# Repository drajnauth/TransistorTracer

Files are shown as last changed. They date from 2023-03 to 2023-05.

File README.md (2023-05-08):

# TransistorTracer
Hardware and software for transistor tracer project.

KiCad PCB files for various versions of the transistor tracer as well as PlatformIO files for the firmware for the Arduino Nano.
The documentation folder contains a pdf version of a PowerPoint presentation regarding the tracer as well as build and operation instructions

A presentation introducing the tracer can be found at https://youtu.be/t6_chWRdSyg.  
This video is a bit dated and some of the information regarding the build, calibration and usage may have changed.

Currently only Hardware version 1 is documented and is working. Other versions are experimental and has not been verified. The software for experimental board versions may not work.

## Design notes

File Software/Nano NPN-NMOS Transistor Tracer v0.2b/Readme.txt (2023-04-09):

The current version is v0.2b
- New features include 
1) Ability to set output voltage.  Prior version only allowed setting of the PWM control voltage.
2) Moved some help messages and error message to flash memory to conserve ram.
3) Other minor changes.

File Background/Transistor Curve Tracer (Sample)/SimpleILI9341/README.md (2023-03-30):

# SimpleILI9341

This is a standalone library that contains both graphics functions
and the TFT ILI9341 driver library.

It is a "slow" version which shares the SPI bus politely with other devices.

It is written in plain C.

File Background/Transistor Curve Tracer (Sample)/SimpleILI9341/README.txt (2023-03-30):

This is a standalone library that contains both graphics functions
and the TFT ILI9341 driver library.

It is a "slow" version which shares the SPI bus politely with other devices.

It is written in plain C.

===============================================================

This library has been derived from the Adafruit_GFX and driver library with
further code from other authors.

===============================================================
Hereafter is the original README text for the Adafruit library:
===============================================================

This is the core graphics library for all our displays, providing
a common set of graphics primitives (points, lines, circles, etc.).

It needs to be paired with a hardware-specific library for each
display device we carry (to handle the lower-level functions).

Adafruit invests time and resources providing this open source
code, please support Adafruit and open-source hardware by
purchasing products from Adafruit!

Written by Limor Fried/Ladyada for Adafruit Industries.
BSD license, check license.txt for more information.
All text above must be included in any redistribution.

===============================================================

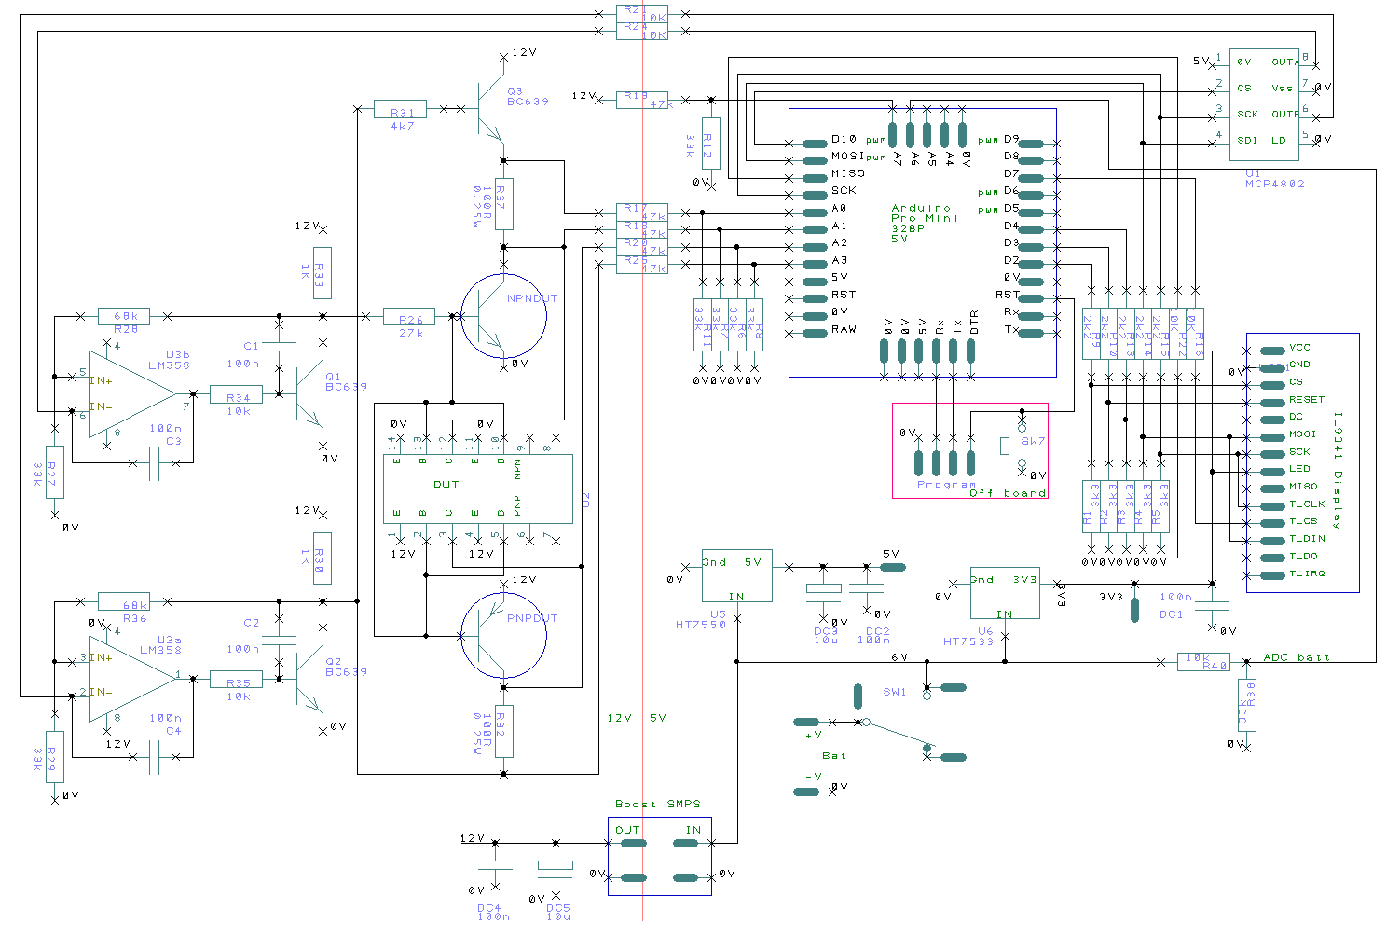
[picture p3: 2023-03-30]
Background/Transistor Curve Tracer (Sample)/ctcircuit.png

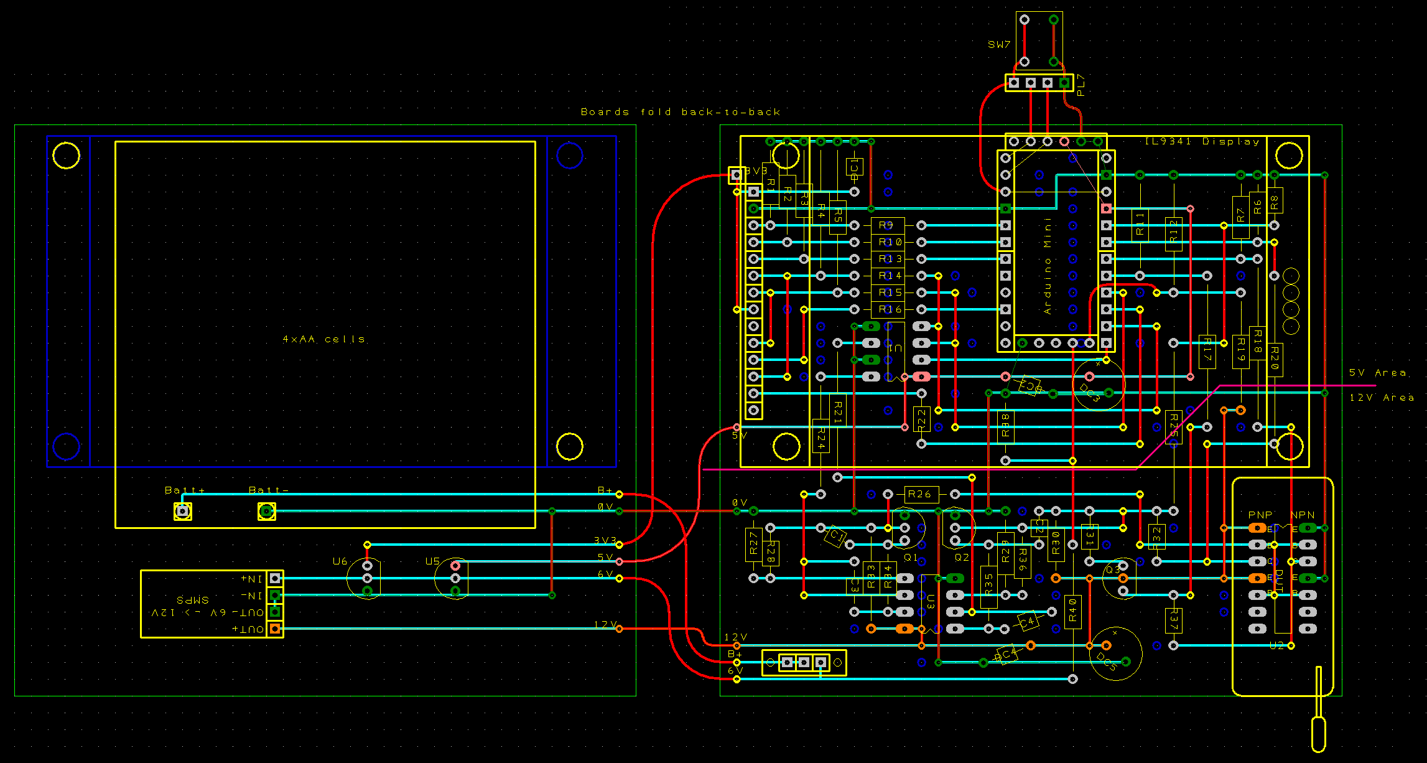
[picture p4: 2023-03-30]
Background/Transistor Curve Tracer (Sample)/ctstripboard.png

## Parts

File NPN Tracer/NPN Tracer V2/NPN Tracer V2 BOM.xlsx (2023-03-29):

Component Count: | 59
Ref | Qnty | Value | Cmp name | Footprint | Description
ADC1, ADC2, ADC3, ADC4, | 4 | 10K | R_Potentiometer_Trim | Potentiometer_THT:Potentiometer_Bourns_3296W_Vertical | Trim-potentiometer
C1, C2, C4, C5, C6, | 5 | 1n | C | Capacitor_SMD:C_1206_3216Metric | Unpolarized capacitor
C11, | 1 | 10u | C_Polarized | Capacitor_THT:CP_Radial_D8.0mm_P2.50mm | Polarized capacitor
C3, | 1 | 100n | C | Capacitor_SMD:C_1206_3216Metric | Unpolarized capacitor
C7, C8, C9, C10, | 4 | 33u | C_Polarized | Capacitor_THT:CP_Radial_D8.0mm_P2.50mm | Polarized capacitor
D1, D2, D3, D4, D5, | 5 | 4.9V | D_Zener | Diode_SMD:D_SOD-323 | Zener diode
D6, | 1 | PWR | LED | LED_THT:LED_D3.0mm | Light emitting diode
D7, | 1 | 1N5817 | 1N5817 | Diode_THT:D_DO-41_SOD81_P10.16mm_Horizontal | 20V 1A Schottky Barrier Rectifier Diode, DO-41
J1, | 1 | RC_SEL | Conn_01x03 | Connector_PinHeader_2.54mm:PinHeader_1x03_P2.54mm_Vertical | Generic connector, single row, 01x03, script generated (kicad-library-utils/schlib/autogen/connector/)
J2, | 1 | AD2 | Conn_01x02 | Connector_PinHeader_2.54mm:PinHeader_1x02_P2.54mm_Vertical | Generic connector, single row, 01x02, script generated (kicad-library-utils/schlib/autogen/connector/)
J3, | 1 | AD1 | Conn_01x02 | Connector_PinHeader_2.54mm:PinHeader_1x02_P2.54mm_Vertical | Generic connector, single row, 01x02, script generated (kicad-library-utils/schlib/autogen/connector/)
J4, | 1 | RB_SEL | Conn_01x03 | Connector_PinHeader_2.54mm:PinHeader_1x03_P2.54mm_Vertical | Generic connector, single row, 01x03, script generated (kicad-library-utils/schlib/autogen/connector/)
J5, | 1 | AD4 | Conn_01x02 | Connector_PinHeader_2.54mm:PinHeader_1x02_P2.54mm_Vertical | Generic connector, single row, 01x02, script generated (kicad-library-utils/schlib/autogen/connector/)
J6, | 1 | AD3 | Conn_01x02 | Connector_PinHeader_2.54mm:PinHeader_1x02_P2.54mm_Vertical | Generic connector, single row, 01x02, script generated (kicad-library-utils/schlib/autogen/connector/)
J7, | 1 | 5V | Conn_01x02 | Connector_PinHeader_2.54mm:PinHeader_1x02_P2.54mm_Vertical | Generic connector, single row, 01x02, script generated (kicad-library-utils/schlib/autogen/connector/)
J8, | 1 | PWR | Conn_01x03 | Connector_PinHeader_2.54mm:PinHeader_1x03_P2.54mm_Vertical | Generic connector, single row, 01x03, script generated (kicad-library-utils/schlib/autogen/connector/)
J9, | 1 | 13.8V MAX | Barrel_Jack | Connector_BarrelJack:BarrelJack_GCT_DCJ200-10-A_Horizontal | DC Barrel Jack
Q1, | 1 | 2SC5706 | 2SC5706-E | Custom_RF:2SC5706
Q2, Q3, Q4, Q5, Q6, | 5 | 2N3904 | 2N3904 | Package_TO_SOT_THT:TO-92_Inline | 0.2A Ic, 40V Vce, Small Signal NPN Transistor, TO-92
R1, R17, | 2 | 1K | R_US | Resistor_SMD:R_1206_3216Metric | Resistor, US symbol
R11, R13, | 2 | 20K | R_US | Resistor_SMD:R_1206_3216Metric | Resistor, US symbol
R15, | 1 | 33 | R_US | Resistor_THT:R_Axial_DIN0411_L9.9mm_D3.6mm_P7.62mm_Vertical | Resistor, US symbol
R16, | 1 | 10 | R_US | Resistor_THT:R_Axial_DIN0411_L9.9mm_D3.6mm_P7.62mm_Vertical | Resistor, US symbol
R2, R18, | 2 | 500 | R_US | Resistor_SMD:R_1206_3216Metric | Resistor, US symbol
R3, R4, R12, R14, R19, | 5 | 200 | R_US | Resistor_SMD:R_1206_3216Metric | Resistor, US symbol
R5, R6, | 2 | 237 | R_US | Resistor_SMD:R_1206_3216Metric | Resistor, US symbol
R7, R8, | 2 | 249 | R_US | Resistor_SMD:R_1206_3216Metric | Resistor, US symbol
R9, R10, | 2 | 56K | R_US | Resistor_SMD:R_1206_3216Metric | Resistor, US symbol
TB1, | 1 | Nano | ARDUINO_NANO | Microcontrollers:SHIELD_ARDUINO_NANO
U1, | 1 | LM7805 | LM7805_TO220 | Package_TO_SOT_THT:TO-220-3_Vertical | Positive 1A 35V Linear Regulator, Fixed Output 5V, TO-220
ZX1, | 1 | 16PIN ZIF | 16Pin ZIF | Custom_RF:16Pin ZIF

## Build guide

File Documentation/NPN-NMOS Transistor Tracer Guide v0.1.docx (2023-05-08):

NPN-NMOS TRANSISTOR TRACER MANUAL

HARDWARE: V1 Software: V0.2b

DRAFT DOCUMENT

Dave Rajnauth, VE3OOI

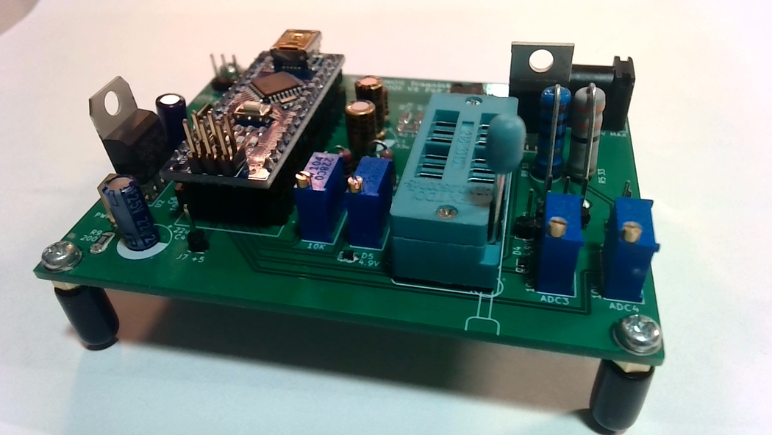
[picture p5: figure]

# Authors Notes

This device was designed only to perform analysis on NPN Bipolar Junction Transistors, N-Channel Enhancement Mode MOSFETS as well as Diodes including Zener Diodes.

Both the hardware and software are provided with NO WARRENTY or SUPPORT. You are on your own.

Various documents and files for this project are hosted on GitHub (https://github.com/drajnauth/TransistorTracer). This includes PCB boards (KiCad files and gerbers), software, and documentation (including this document).

This document includes very important information, and you need to read the contents carefully. Failure to read and follow the instructions in the document WILL cause headaches and may cause you to pitch the board against a wall.

This document uses the following syntax:

1. Anything in Red indicates something very important which could negatively impact the board. Please read carefully.
2. Anything in Deep Red indicates a particularly important note. Please pay attention.
3. Commands are highlighted in orange.
4. Changes to parameters defined by the Arduino #define directive are also highlighted in orange.

Finally, this is a powerful tool, and you are expected to understand how a transistor works and why you need the various traces detailed in this document. It has features which can make your day or frustrate the heck out of you.

# Hardware Build Notes

1. Have a copy of the schematic available during the build.
2. DO NOT INSERT THE ARDUINO AND POWER UP (i.e., Apply Vcc) BEFORE CALIBRATION IS DONE
3. Do your best to get parts as labelled.
4. Early versions of boards have incorrect silkscreen values for POTS. They MUST be 100K.
5. The TIP120 can be replaced with a 2SC5706 power transistor.
6. The 1N5817 can be replaced with any 1 Amp Shottky Diode
7. The board can be powered from either J8 or J5. Maximum voltage is 14 V. Exceeding this could damage your Arduino.
8. R1, R3, R6, R7, R10, and R11 resistors cannot be substituted and need to be as close as possible to the indicated values. Substituting resistor values could dramatically alter the performance of the device.
  - R1 and R3, in combination with C1 and C2, are part of a low pass filter that converts an Arduino generated PWM signal into a DC voltage.
  - R6 and R7 set the gain for the LM386 Opamp to amply the PWM generated DC voltage to Vcc to control the TIP120/2SC5806 power transistor.
  - R10 and R11 form a voltage divider to allow the Arduino to measure the value of Vcc.
9. Capacitors C1, C2, C7, C8, C9 and C10 cannot be substituted and need to be as close as possible to the indicated values. Other capacitors can use similar values but not exact values.
  - C1 and C2 are part of a low pass filter to convert the Arduino generated PWM signal to a DC value.
  - C7, C8, C9 and C10 also form a low pass filter to smooth out the voltages read by the Arduino ADC. Values too large here will result in ADC errors.
10. The D3, D4, D5, and D6 4.9V Zener diodes are optional and are there to protect Arduino ADC from overvoltage. They are not necessary for the operation of the device.
11. Resistors R10 and R11 form a voltage divider to allow the Arduino to measure the value of Vcc. If you change these values, ensure the ratio will allow 14V to deliver about 4.8V to the Arduino. Measure and note the values, rounding to the nearest whole number, of the resistors you use. You will need to enter them in the Arduino code during the calibration.
12. R4, R5 and R8 set the maximum current to the base/gate or to the collector/drain of the transistor under test. You can substitute values here. Keep R4 close the 500R (i.e., within 10 or 20R). R5 and R8 must be 2W resistors. They dissipate heat from several hundred milliamps of current. Measure both resistors with Volt Ohm Meter and note the values, rounding to the nearest whole number, of these resistors. You will need to enter them in the Arduino code.
  - You are provided with two resistor values to limit the current delivered to the collector/drain. You can select R5 or R8 via jumper J4 (RCSEL). Whenever you change this jumper you must change the resistor value via the Arduino CLI. See the CLI Resistor Configuration Commands section.
13. Solder all SMT parts first.
14. Solder all through hole components from the underside
  - Arrange the pots such that turning clockwise increases the resistance between the wiper and the grounded leg.
15. Once you are finished remove all jumpers from header pins. Do NOT insert the Arduino. Power up and check LED operation and check for appropriate voltages at Arduino +5V pin and LM358 Vcc pin (pin 8).
16. Disconnect power and proceed to calibration.

# Calibration

Note the instructions below are for hardware Version 1 and software version 0.1b.

1. DO NOT CONNECT ARDUINO AND POWER UP THE BOARD BEFORE CALIBRATION IS DONE. Failure to do so may result in damage to the Arduino.
2. For all measurements, use one consistent VOM. Try not to use different meters as they may introduce additional errors.
3. Before powering up Arduino, you need to calibrate pots to not damage the Arduino’s ADC pins.
4. Remove Arduino. Remove all jumpers from all trim pot jumper headers pins.
5. Connect Vcc to the board and measure the voltage at the +5V terminal pin (J7). Record the voltage.
6. Connect a jumper wire from +5V terminal to each pot’s jumper “+” pin (J1, J2, J6, J3). “+” is marked on the silkscreen. The plus pin is connected to the top end of the pot. The wiper is connected to the Arduino’s ADC and forms a voltage divider.
  - Adjust each pot until you get as close as possible to 1.75V output at the pot’s wiper.
7. Verify the voltage at ADC 0 pin and Digital Pin 12 (or junction of R10 and R11) is below 5 Volts. If this voltage is above 5V, you need to verify the value of Vcc (less than 14V) and the values of R10 and R11. Ensure solder joins are good.
  - Note that Resistor R10 and R11 form a voltage divider to convert Vcc to a voltage below 5V. The Arduino reads this voltage to ensure a proper Vcc is applied to the board.
8. Once all pots are adjusted and the Vcc voltage divider is working, then there is little danger in damaging the Arduino’s ADC. Insert Arduino and load the code. See the software loading section of this document.
9. Connect via TTY console to Arduino. Enter the C R command to display all ADC values from each pot.
10. Note that each pot has ADC1, ADC2, ADC3, ADC4 marked on the silkscreen. Each jumper associated with the pot is marked as AD1, AD2, AD3, AD4. This corresponds to the ADC number on the Arduino.
11. Connect 5V to the same jumper in step 3. Note the ADC number of the jumper and pot.
  - Adjust the pot’s wiper (fine adjust needed) until the corresponding ADC displayed by the Arduino is EXACTLY 364. Repeat for all jumpers/pots.
  - Measure and record the voltage at the wiper of the adjusted pot. It may be slightly different from the initial 1.75V setting.
  - Enter the R command to reset the Arduino when done.
12. Complete and record the following calculations for each pot:

Note V(wiper) is the updated wiper voltage you measured in the prior step and V(applied) is the voltage you measured previously at the +5V pin (J7). ADC_Value is the value of the ADC that you set the pots to (i.e., 364).

For the example calculations below V(wiper)=1.75, V(applied)=5, ADC_Value=364. Subsititue the values you measured.

  - Calculate VOLTAGE_DIVIDER = V(wiper)/V(applied)

e.g., 1.75/5 = 0.357

Note V(wiper) is the updated voltage you measured in the prior step.

  - Calculate ADC_CONVERSION = ADC_Value/V(wiper) e.g., 364/1.75 = 208.0
  - Calculate VOLTAGE_CONVERSION = VOLTAGE_DIVIDER * ADC_CONVERSION e.g., 0.357*208 = 78.0
13. Take the VOLTAGE_CONVERSION and update the #define ADC_CONVERSION ((float)78.0) in the defines.h file. This can be done after loading the program into the Arduino IDE.
14. Using the measured resistor values for R10 and R11 calculate the voltage divider for the Vcc voltage sensing. Calculate the divider R11/(R11+R10). Next calculate the ADC conversion ratio by taking the voltage measured at the J7 pin (+5V pin) and dividing it by 1024. Update the #define VOLTAGE_SENSE_CONVERSION parameter in the defines.h file.

For example,

Suppose resistor divider measurements are R10 is 991 and R11 is 497. Divider is 497/(497+991)=0.3340

Suppose voltage at J7 pin is 4.88V so ADC Voltage conversion is 4.88V/1024 = 4.766mV. i.e., 1 ADC count is 4.766mV

With resistive divider each count is 4.766mV/0.3340 = 14.26mV = 0.01426V

#define VOLTAGE_SENSE_CONVERSION 0.01426

15. Use your measurements for the Base and Collector resistors to update the following defines in the defines.h file.

For example, RC resistors are 32 and 10. The base resistor is 462.

#define RC_RESISTORHIGH 32

#define RC_RESISTORLOW 10

#define RB_RESISTOR 462

1. Reset the Arduino and measure the max voltage generated by the Arduino PWM circuit for the base/gate and collector/drain. Ensure no jumpers are connected. Enter the P 3 255 command and measure and record the voltage after the 200R resistor connected to D3 pin (i.e., the side of the R1 200R resistor connected to the electrolytic capacitor). Reset the Arduino and repeat for pin 10. Enter the P 10 255 and measure and record the voltage after the R3 200R resistor is connected to D10 pin. Again, measure the voltage at the side of the resistor that is connected to the electrolytic capacitor. Update the following defines in the defines.h file with the voltages you measured. In the example below, 4.6 volts was measured.

#define MAX_VC_VOLTAGE 4.6

#define MAX_VB_VOLTAGE 4.6

2. Save all modified files. Compile and load the Arduino program before continuing. The above defines must be in place.
3. Complete the following. DO NO RESET OR POWER OFF ARDUINO UNTIL ALL STEPS BELOW ARE COMPLETE. Failure will result in redoing the steps.
  1. Set the base resistor value using the S R B nnnn command where nnnn is the resistor value that you measured and entered previously. E.g., enter S R B 462 to set the base resistor to 462.
  2. Set the jumper J4 (RCSEL) to a resistor for the sweep. Use the S R C nnnn command to define the Collector resistor nnnn that the jumper has selected. E.g., Enter S R C 10 to set the collector resistor set by the jumper J4 to be the 10R resistor. Alternatively, enter S R C 32 if the jumper J4 has selected the 32R resistor.
  3. Connect Vcc to the board. If you change Vcc, the following calibration step needs to be repeated. E.g., if you use 12V to calibrate the board and you connect 13.8V in the future, the board will need to be recalibrated for the new Vcc value.
  4. The final calibration step is to get the Arduino to measure the min and max voltages available when generating a trace. Insert jumpers in J1, J2, J6, & J3. Ensure there is nothing connected to the ZIF socket. Enter the C M command. This takes a few minutes to complete. If you miss this step, the tracer will not work properly.
4. Update the EEPROM with the configuration by entering the E W command. If you miss this step, the tracer will not work properly next time it’s restarted. The Arduino will now power up with the values you defined above.
5. Your transistor curve tracer (V1) is now ready.

# Transistor Tracer Software

The transistor tracer needs two software components:

1. The Tracer uses an Arduino Nana with special software that controls the hardware and produces the various traces.
2. The Tracer also requires an external plotting program. A small versitile Python program was written to generate generic plots. This program is one option that can be used to generate plots on the fly. A second option is to use another program such as Microsoft Excel or Apache OpenOffice Calc to generate the charts. The Arduino software simply displays the data to be charted on the serial console which can be copied and pasted into any other charting program.

## Arduino Nano Firmware

This software for the Arduino Nano was written using Visual Code with the PlatformIO plugin instead of the Arduino IDE. The transistor tracer software is FULLY compatible with the Arduino IDE. If you are familiar with PlatformIO, I suggest you create a new Visual Studio project for Platform IO and load the source files. Directions to accomplish this using Visual Studio is beyond the scope of this document. Instead, directions for loading using Arduino IDE will be given below.

It is assumed that you understand how to use the Arduino IDE to compile and load sketches on Arduino boards. If you are new to using the Arduino IDE, I suggest that you review tutorials on the internet to prepare you. However, I strongly suggest you seek assistance from someone that is familiar with the Arduino IDE to reduce your stress and increase your chances of success.

Arduino IDE Loading Instructions

1. From the https://github.com/drajnauth/TransistorTracer github repo, download the zip file for the entire repo. This will duplicate all files in the repo.
2. Create a directory on your local hard disk and provide a name that you would like to call the Arduino sketch (e.g., “TransistorTracerSketch”).
3. Copy all the files from the “Software/Nano NPN-NMOS Transistor Tracer v0.2b” directory to the above created directory.
4. Rename the main.cpp file so it matches the directory name you created with an .ino extension (e.g. TransistorTracerSketch.ino)
5. Double click the ino file or open the sketch in your Arduino IDE.
6. Ensure you have the Arduino Nano board selected and the appropriate com port selected. Complete a test compile to ensure it compiles.
7. Load the software on the nano.
8. Once the software is loaded, the onboard LED should blink every second indicating Vcc is not connected. If you connect via the Arduino Console, there will be a Vcc error displayed. This is normal until the Nano is inserted onto the tracer board and the board is powered up. DO NOT INSERT THE ARDUINO AND POWER UP THE BOARD BEFORE CALIBRATION IS DONE.

## Microcontroller Console Python Program

The console program was written to plot data from any microcontroller. It WAS NOT written exclusively for the transistor tracer. The program was meant to be a quick and dirty program that can plot charts from any TTY (serial port) connected microcontroller. A display could have been incorporated onto the Arduino, however this would make this project complex, and the Nano software would be a beast to write and maintain.

Figure 1: Sample Plot from Python Program

You can also copy and paste the generated data from the Arduino Console into Microsoft Excel or Apache OpenOffice Calc and generate the charts yourself. The Arduino simply outputs the data to the console and the python program captures it, stores it into a buffer and then plots the data for you.

A presentation was provided giving a high-level overview of how this program works. The associated ppt has been included in the documentation folder and you should refer to this regarding how to use the python program.

If you are familiar with python and loading libraries, then load the source code and associated libraries. Python files are in the “Software/Python Microcontroller PC Console” directory.

However, if you are not familiar with python an executable file is provided in the python directory. The file’s extension is. ex_. Once you have this file on your local PC, rename the file to be .exe. Some browsers will block you from downloading executable files and this is a crude attempt to circumvent such checks.

Simply double click the executable and accept the warning about the software being unverified. Do this at your own risk. The software I placed on my repo is free of malware.

Note that the program will give an error if no com ports were detected. You must plug in your Arduino to the USB port before running the console program.

Figure 2: Python Program Interface

# Command Line Interface

The Arduino has a command line interface (CLI) which is accessible via a terminal emulator connected to the Arduino USB connection. That is, a serial comport connection from your PC using either the Arduino console program or the Python console program. The CLI may be accessed via any TTY console program (e.g., putty). This is the only way to control the transistor tracer.

## Performing Sweeps

1. The transistor tracer generates a trace by sweeping a set of voltages. These DC voltages are generated by the PWM circuit.
  - There is a base/gate PWM voltage (Pin 3) that is applied directly to the transistor under test.
  - There is a Vcc PWM voltage (Pin 10) that is amplified by the LM358 opamp and a high-power transistor (TIP120 or SC5706) in a common emitter configuration.
2. There is a “Control” voltage. There is also an “Output” voltage.
  - The “Control” voltage is generated by the Arduino PWM circuit.
  - The “Output” voltage is delivered to the device under test (DUT).
  - The conversation between the “Control” and “Output” voltages is calculated when you perform a calibration.
3. The arduino uses the “Control” voltage to sweep voltages to complete a trace. It does not use “Output” voltages. “Output” voltages are measured by the ADCs.
4. Since the base/gate “Control” voltage is fed directly to the transistor under test, the base/gate voltage is essentially the “Output” voltage to the transistor. However, since the Vcc “Control” voltage is amplified, the “Output” voltage fed to the collector/drain of the transistor under test is larger than the “Control”.
5. When you set voltage ranges, you are setting the “Control” voltage that the Arduino outputs. However, you can set the “Output” voltage range and the Arduino will calculate the “Control” voltage for you and use that.
6. Normally, the calibration will calculate the minimum and maximum voltages available and use those values for the sweep. However, you can manually set the “Control” or “Output” sweep voltages using the S I or S O commands. Once again, if you set “Output” voltages, the Arduino converts this into “Control” voltages which are used for tracing.
7. You can also manually set the voltage delivered to the DUT using the S V command. This only uses the “Control” voltage. However, this is a one-time setting. It’s not used in a sweep. BE CAREFULL SETTING VOLTAGES MANUALLY – you could destroy (i.e., burn out) the collector resistor or the transistor under test if you exceed its maximum ratings.
  - When you set voltage ranges, you are restricting values that the Arduino will deliver to the DUT. This restricts values that the S V command can use.
8. MOST IMPORTANT: Voltages are entered in mV (Milla Volts). i.e., to specific 1 volt you enter 1000 mV. The CLI does not support floating point or real numbers. Only integers can be entered.

The following diagram details the pin out for the Zif sockets. Ensure transistors are connected properly. Incorrect orientation would result in “wonky” charts and in extreme cases damage to the transistor or resistors on the board.

## CLI Summary

Commands listed below follow a specific syntax. Anything in [ ] means that additional input is needed. Either a sub command or a number. Note that numbers MUST BE INTEGERS. Floating point or real numbers are not supported. For example, to ensure a real number multiply it by 1000 e.g., voltages are entered in millivolts.

The | character indicates an or condition. Either of the values on either side of the | can be entered buy not both. E.g., C [R|M] means that C R or C M can be entered i.e., R OR M can be entered.

The Arduino tracer store it configuration to is local EEPROM. The EEPROM is not updated when configuration is changed. You must explicitly save the running configuration to the EEPROM configuration.

Note that Gate-Base, Collector-Drain, and Emitter-Source are the same. i.e., anything defined for base will also apply to gate.

- H Help – Command summary
- C Display current Calibration
- C [R|M] Calibrate commands
  - R display raw ADC values repeatedly until the arduino is reset
  - M identifies the min and max voltage that can be provided to the transistor under test
- D Set default values. Resets all running configuration to default.

Reboot or reset to restore the EEPROM calibration.

Run the C M command to reset the min and max available voltages.

- E [I|R|W] Manage EEPROM
  - I is used to initialize the EEPROM to factory default
  - R is used to read and use the configuration in EEPROM
  - W is used to write the current running configuration to EEPROM. This will be loaded when arduino is powered on or reset.
- M Measure and display voltages
- P [3|10] [255] Set PWM on pin 3 or pin 10 to duty cycle from 1 to 255
- R Reset the arduino. EEPROM configuration is loaded.
- S V [B|C] [v] Manually set voltage v in mV
  - B is used to set the voltage for the Base/gate pin.
  - C is used to set the voltage for the collector/drain pin.
- S U [D|M|U] Set default units for output. Decimal [D], Milla[M] or Micro [U]
- S I [B|C] [min] [max] Set input or control min max voltage generated by Arduino
  - B sets the base/gate control voltage to sweep from min to max in mV.
  - C sets the collector/drain control voltage to sweep from min to max in mV.
  - Increment auto calculated based on number of data point “P” defined below
- S O [B|C] [min] [max] Set output min max voltage delivered to transistor to sweep
  - B sets the base/gate voltage to sweep from min to max in mV.
  - C sets the collector/drain voltage to sweep from min to max in mV.
  - Increment auto calculated based on number of data point “P” defined below
- S R [B|C] [r] Set Base or Collector resistor value to r.
  - r must be configures during calibration.
  - For collector/drain, resistor is set by jumper J4 (RCSEL). Base/gate resistor is fixed and cannot be changed for this version of hardware board. Subsequent hardware versions will have different base/gate resistors.
- S P [B|C] [n] Set number of data points n to sweep between max and min
  - This is used to calculate the increment between min and max voltages defined above
  - B sets the number of data point to sweep for base/gate voltages/currents
  - C sets the number of data point to sweep for collector/drain voltages
- T N [I|IV|O|B|BC|R|G] Trace NPN Transistor
  - I - Perform an input trace. Trace Vbe vs Ic
  - IV – Perform an input trace with Vce. Trace Vbe vs Vce
  - O – Perform an output trace. Trace Vce vs Ic for various Ib values
  - B – Perform a beta trace. Trace Ib vs B
  - BC – Perform a beta trace. Trace Ic vs Bc
  - R – Perform a re trace. Trace Vbe vs re
  - G – perform a transconductance trace. Trace Vbe vs gm
- T F [I|IV|O|K|G|R] Trace N Chan MOSFET
  - I - Perform an input trace. Trace Vgs vs Id
  - IV – Perform an input trace with Vgs. Trace Vgs vs Vds
  - O – Perform an output trace. Trace Vds vs Id for various Vgs values
  - K – Perform a FET constant K trace. Trace Id vs K
  - G – perform a transconductance trace. Trace Vgs vs gm
  - R – Perform a Rds trace. Trace Vgs vs Rds
- T [I|O] Trace Diode
  - I – perform an input trace. Diode inserted between base/gate and emitter/source pins.
  - O – perform an output diode trace. A resistor must be connected in series with resistor to allow the Rc resistors not to burn up. Use resistor around 200R.

## CLI Calibration Commands

This section summarizes all the commands available for calibration and configuration viewing. There are 3 commands available.

C

Display current Calibration values and the defined configuration that is currently running. This may not show the configuration that is stored in the EEPROM. E.g., you changed the configuration and did not write it to the EEPROM.

C M

Connect the Tracer to Vcc with empty socket (nothing connected) to determine the voltage sweep range for base/gate voltage and collector/drain voltage. It also calculates the conversion constants to generate output voltage as a function of control voltage.

C R

Connect the Tracer to Vcc with empty socket (nothing connected). Enter this command to display the raw ADC values repeatedly. The first column is the Vcc voltage pin (AD4), next is Vc voltage pin (AD3), Vbcontrol pin (AD1), Vb voltage pin (AD2). Press the reset button or enter the R command to reset the Arduino and stop the display.

## CLI Resistor Configuration Commands

This section summarizes all the commands available for changing the resistor values.

S R C nnnn

Use the resistor value for the collector/drain (R5 or R5) specified by nnnn. Note that nnnn must be a integer number (i.e., not real or floating point number) that was set in the defines.h file during the calibration.

S R B nnnn

For this version of the transistor tracer hardware, the base/gate resistor is fixed and this command is unsupported. It will be available for a subsequent hardware revision where you can select the base/gate resistor.

S R

Display the current base/gate and collector/drain resistor that the Arduino will use for current calculation.

## CLI NPN Sweep Commands

The T command is used to complete Traces. The T N command is used to complete NPN Transistor traces.

1. The following traces use the configured min and max voltages. You can adjust sweep voltages and number of data points (resolution) to be taken during a sweep. Use the S M command to adjust min & max voltages for and S P to set data points.
2. The following below outlines the various traces:
I. Input Trace: T N I
  - This command sets the Vcc voltage to the maximum available voltage and then sweeps the base voltage from configured min to max at define inc (resolution). It prints out Vbe vs Ic.
II. Input Trace: T N I V
  - This command is the same as above except it prints out Vbe vs Vce.
III. Output Trace: T N O
  - This command sweeps the base voltage from configurated min to max with inc. For each base voltage, it then sweeps Vcc from configured min to max at defined inc. For each base voltage it prints out Vce vs Ic in the form Ib, Vce, Ic.
IV. Beta Trace: T N B
  - This command sets the Vcc voltage to the maximum available voltage and then sweeps the base voltage from configured min to max at define inc (resolution). It calculates transistor beta and prints out Ib vs Beta.
V. Beta Trace: T N B C
  - This command is the same as above except it prints out prints out Ic vs Beta.
VI. Beta Trace: T N R
  - This command sets the Vcc voltage to the maximum available voltage and then sweeps the base voltage from configured min to max at define inc (resolution). It calculates transistor re (intrinsic resistance) and prints out Ic vs re.
VII. Beta Trace: T N G
  - This command sets the Vcc voltage to the maximum available voltage and then sweeps the base voltage from configured min to max at define inc (resolution). It calculates transistor transconductance and prints out Ic vs gm

## CLI N-Channel MOSFET Sweep Commands

The T command is used to complete both NPN and N-Channel Enhancement Mode MOSFET Traces. The T F command is used to complete N channel MOSFET traces.

1. The following traces use the configured min and max voltages. You can adjust sweep voltages and number of data points (resolution) to be taken during a sweep. Use the S M command to adjust min & max voltages for and S P to set data points.
2. The following below outlines the various traces:
I. Input Trace: T F I
  - This command sets the Vcc voltage to the maximum available voltage and then sweeps the gate voltage from configured min to max at define inc (resolution). It prints out Vgs vs Id.
II. Input Trace: T F I V
  - This command is the same as above except it prints out Vgs vs Vds.
III. Output Trace: T F O
  - This command sweeps the base voltage from configurated min to max with inc. For each gate voltage, it then sweeps Vcc from configured min to max at defined inc. For each gate voltage it prints out Vds vs Id in the form Id, Vgs, Id.
IV. Intrinsic Resistance Trace: T F R
  - This command sets the Vcc voltage to the maximum available voltage and then sweeps the gate voltage from configured min to max at define inc (resolution). It calculates transistor re (intrinsic resistance) and prints out Id vs Rds.
V. Transconductance Trace: T F G
  - This command sets the Vcc voltage to the maximum available voltage and then sweeps the gate voltage from configured min to max at define inc (resolution). It calculates transistor transconductance and prints out Id vs gm
VI. Transconductance Trace: T F K
  - This command is the same as above except it it calculates transistor transconductance constant K and prints out Id vs K.

## CLI Diode Sweep Commands

The T command is used to complete both NPN and N-Channel Enhancement Mode MOSFET Traces. As well as diode Traces. The T D command is used to complete diode traces

The following traces use the configured min and max voltages. You can adjust sweep voltages and number of data points (resolution) to be taken during a sweep. Use the S M command to adjust min & max voltages for and S P to set data points.

1. Note that the diode MUST be oriented correctly in the socket.
2. The following outlines the various traces:
  i. Input Trace: T D I

This traces the turn on voltage of the diode for it to conduct from its anode to cathode terminals. The diode must be connected between the base/gate socket and ground. The cathode is connected to emitter/source socket (ground). For a Zener diode, it’s reversed, the cathode is connected to the base. The collector/drain pin of the zif socket MUST be unconnected. This command sweeps the base/gate voltage from configured min to max at define inc (resolution). It prints out Vb vs Id

  ii. Output Trace: T D O

This trace identifes the voltage drop across the diode’s anode to cathode. The diode will need a resistor connected between the cathode and the emitter/source socket (ground). The resistor is selected to NOT exceed the maximum current the diode can handle. The resistor also protects the Arduino pin used for base PWM output (pin 3). Failure to add a resistor could cause damage to the Arduino. This command sets the base/gate voltage Arduino pin to zero to sink current. It then sweeps the Vcc voltage from configurated min to max with inc. For each Vcc voltage, it measures the voltage drop across the collector/drain to the base/gate sockets along with current. It prints out Vf vs I.

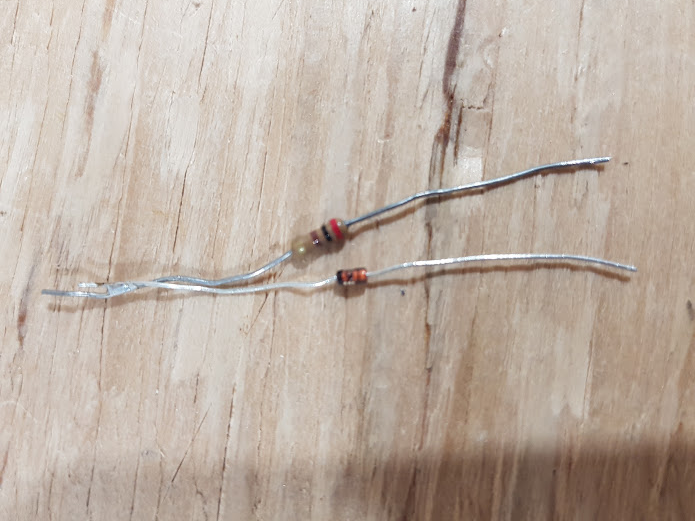
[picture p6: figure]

Figure 3: Diode Connected to Resistor

## CLI Sweep Limits Commands

The S command can be used to set various parameters that customize sweeps.

1. For base/gate voltage there is a min voltage and max voltage that can be set. The calibration command C M is used to set the default min and max voltage available.
2. As detailed previously (see Command Line Interface section) the Arduino sets a “Control” voltage which translates to an “Output” voltage that is delivered to the transistor under test. You can enter set the min and max “Control” or “Output” voltages. Recall the Control voltage is the PWM voltage output from the Arduino. The Output voltage is the voltage delivered to the Device Under Test (DUT).
3. Values MUST be entered as Millivolts (mV) e.g., 4V entered at 4000.
4. The following outlines the various configuration command options:
I. Base/Gate Sweep: S I B xxxx yyyy
  - This command sets the Control minimum voltage (xxxx) and the maximum voltage (yyyy) for the base/gate PWM pin. The voltage increment used for a trace is automatically calculated to the number of data points defined. Default is determined by C M calibration command.
II. Base/Gate Sweep: S O B xxxx yyyy
  - Same as above except you are specifying the “Output” voltages and the Arduino will calculate the “Control” voltages using the calibration that was performed.
III. Vcc Sweep: S I C xxxx yyyy
  - This command sets the Control minimum voltage (xxxx) and the maximum voltage (yyyy) for the Vcc PWM pin. The increment used for trace is automatically calculated to the number of data point defined. Default is determined by C M calibration command.
  - Input sweeps use the maximum Vcc voltage. Therefore, you can manually reduce the Vcc voltage (e.g., for Vce(sat)) used for input sweeps by setting the maximum Vcc voltage.
IV. Vcc Sweep: S O C xxxx yyyy
  - Same as above except you are specifying the “Output” voltages and the Arduino will calculate the “Control” voltages using the calibration that was performed.

You need to enter the E W command to update the EEPROM configuration values or else these definitions will be lost at the next restart of the Arduino.

## CLI Sweep Data Points Commands

The S command can also be used to set the number of values to sweep between the min and max you defined in the prior section. You can set the number of data points to be taken during a typical sweep.

Note that some sweeps such as the beta, gm, K and Rds and re sweeps typically use 25% of the increment regardless of the defined value. This is because it requires greater resolution to perform the calculations.

Example:

- If the min base/gate voltage is 0.01V and the max voltage is 4.6V
- If you set the number of points to 10, then the increment used during a sweep is (4.6 – 0.01)/10 = 0.45V
- Therefore, during a sweep, 10 measurements are taken with each increasing by 0.45V from min to max.

The following below outlines the various configuration options:

I. Base/Gate Sweep: S P B xxxx
  - This command sets the number of data points (xxxx) to measure during a sweep of the base/gate voltage. The increment used for sweep is automatically calculated. This can give a smaller step size (e.g., increment of 0.1V instead of 0.4V). Default is 10 data points for base/gate.
  - The range of allowed data points is defined in the defines.h file as:

#define MIN_NUM_VB_VOLTAGE 5 // Maximum allows points for collector/drain sweep

#define MAX_NUM_VB_VOLTAGE 20 // Maximum allows points for base/gate sweep

#define NUM_VB_VOLTAGE 10 // Default number of points

II. Vcc Sweep: S P C xxxx
  - This command sets the number of data points (xxxx) to measure during a sweep of the collector/drain voltage. The increment used for sweep is automatically calculated. This can give a smaller step size (e.g., increment of 0.1V instead of 0.4V). Default is 10 data points for collector/drain.
  - The range of allowed data points is defined in the defines.h file as:

#define MIN_NUM_VB_VOLTAGE 5 // Maximum allows points for collector/drain sweep

#define MAX_NUM_VB_VOLTAGE 20 // Maximum allows points for base/gate sweep

#define NUM_VC_VOLTAGE 30 // Default number of points

You need to enter the E W command to update the EEPROM configuration values or else this definition will be lost at the next restart of the Arduino.

## CLI EEPROM Management Commands

The Arduino uses a running config that contains the various configuration parameters defined during the calibration. The running configuration is stored in RAM and is restored from a backup copy in EEPROM each time the Arduino is powered on or is reset. Each time the Arduino is reset or is restarted/powered on, it reads the configuration parameters stored in EEPROM and uses it as its running configuration. The configuration stored in EEPROM is typically not used except for the command described in this section.

If you change the running configuration, the configuration stored in the EEPOM is NOT automatically updated.

The E command is used to manage configuration values stored in the EEPROM.

The following commands outlines the various EEPROM configuration options:

I. Read EEPROM: E R
  - This command reads and overwrites the current running configuration with the configuration stored in the EEPROM. Any unsaved changes made to the running configuration will be lost (i.e., changes to voltage ranges, points, resistor values, max voltages, etc.)
II. Write EEPROM: E W
  - This command writes the current configuration to the EEPROM. It overwrites the EEPROM.
III. Initialize EEPROM: E I
  - This command initializes the EEPROM. It first sets the default configuration values using parameters in the defines.h file, and then executes the calibration command (C M) to determine the min and max voltages. Once completed, it writes the resulting configuration to the EEPROM. Think of this as a factory reset.

## CLI Miscellaneous Management Commands

There are a few other MISC commands that can be used. For example, troubleshooting.

I. Set Voltages: S V B xxxx or S V C xxxx
  - This sets the PWM voltage at pin 3 (base/gate voltage) or pin 10 (collector/drain voltage). The voltage is given by xxxx and is in Millivolts (i.e., mV). If O (Oh and not zero) is added after the B or C then, the Arduino tries to set the output voltage delivered to the transistor under test based on the calibration performed. Note that this value could be off by up to 0.5 volts.
  - BE CAREFULL SETTING VOLTAGES MANUALLY – you could destroy a resistor or the transistor under test if you exceed its maximum ratings.
II. Set Units: S U uu
  - Set current units for graph for normal decimal (D), milliamps (M) or microamps (U). uu may be D, M or U. Default is Decimal
  - E.g.,
      - S U D is used for normal decimal,
      - S U M is used for milli and
III. S U U is used for micro. Set PWM: P xx yyy
  - This command manually sets the PWM output of pin 3 or pin 10 of the Arduino and is used for troubleshooting.
  - xx is the pin number (3 or 10) and yyy is the PWM value (1-255). A higher PWM values will output a higher voltage. A value of 128 will give ½ of the maximum output voltage.
IV. Measure: M
  - This reads and displays all the voltages and currents. It assumed you have manually set a voltage using the S P or S V commands.
V. Reset: R
  - This resets the Arduino. This is not the same as a power on. Power off/power on or pressing the Nano reset button does a “hard” reset. This command performs a “soft” reset.
VI. Set Defaults: D
  - This command sets the default parameter to the running config. It does not change the EEPROM config.

# Appendix

## ZIF Socket Pinout

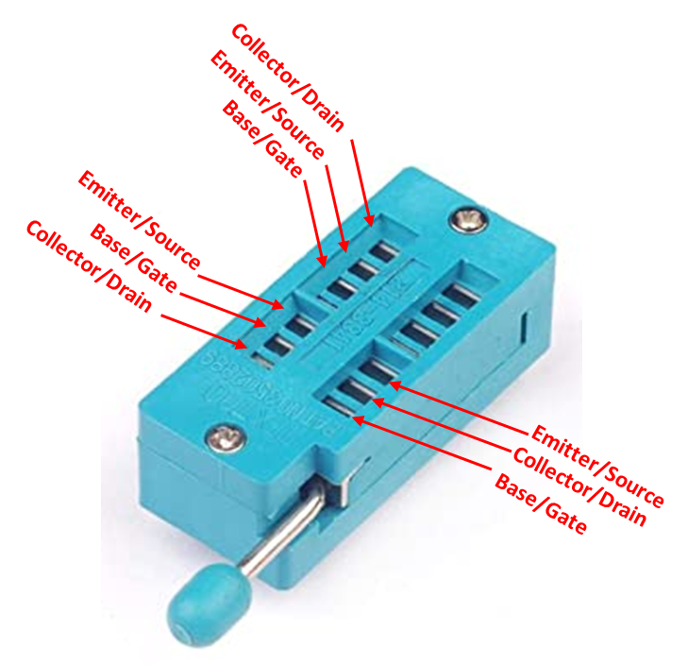
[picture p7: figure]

## Parts List

Ref | Qnty | Value | Cmp name | Notes
ADC1, ADC2, ADC3, ADC4, | 4 | 100K | R_Potentiometer_Trim | Note that some early boards had 10K marked on silkscreen which is incorrect. Correct value is 100K
C1, C2, | 2 | 33u | C_Polarized_US
C3, | 1 | 100n | C
C4, | 1 | 22u | C_Polarized | This is for voltage regulator. Anything around 10 or 20uF is adequate.
C4 | 1 | 1u | C_Polarized | This is for voltage regulator. Anything around 1uF is adequate.
C6, | 1 | 100n | C
C7, C8, C9, C10, | 4 | 1n | C | Optional. Used to reduce noise on ADC line. If ADC values are noisy, then add capacitors around 1nf. Don't make it too large since it must charge up before ADC reads the value on the Pin
D1, | 1 | 1N5817 | 1N5817 | Use any Schottky Diode with low voltage drop and high current. Need about 1-2A
D2, | 1 | PWR | LED | Use any LED with 3mm Footprint with max current of 60mA
D3, D4, D5, D6, | 4 | 4.9V | D_Zener | Optional. Can be omitted. Used to protect Arduino should >5V fed to ADC pins.
J1, | 1 | AD3 | Conn_01x02
J2, | 1 | AD4 | Conn_01x02
J3, | 1 | AD2 | Conn_01x02
J4, | 1 | RCSEL | Conn_01x03
J5, | 1 | PWR | Conn_01x03
J6, | 1 | AD1 | Conn_01x02
J7, | 1 | 5 | Conn_01x01
J8, | 1 | 13.8V MAX | Barrel_Jack | J5/PWR connector can be used instead. Middle pin is power.
Q1, | 1 | TIP120 | TIP120 | Can use any high current transistor. TIP122, 2SC5706 with same TO-220 footprint at TIP120
R1, R3, | 2 | 200 | R_US
R10, | 1 | 1K | R_US | Measure the actual value with VOM and enter it during calibration
R11, | 1 | 499 | R_US | Anything below 523R and around 500R. E.g. 475, 487,499, 511, 523. Measure the actual value with VOM and enter it during calibration
R2, R7, | 2 | 10K | R_US | R2 can be anything around 10K. R7 MUST be 10K
R4, | 1 | 499 | R_US | Use resistor below 500R. I used 462. This limits how much current is delivered to base/gate. Measure the actual value with VOM and enter it during calibration
R5, | 1 | 33 | R_US | Must be 2 Watt resistor. Measure the actual value with VOM and enter it during calibration
R6, | 1 | 4.7K | R_US | This resistor sets the gain of LM358. 4.7K seems to be ok. Might be a little too small (i.e., too much gain) but this value works fine. Calibration command measures the gain
R8, | 1 | 10 | R_US | Must be 2 Watt resistor. Measure the actual value with VOM and enter it during calibration
R9, | 1 | 200 | R_US
TB1, | 1 | NANO | ARDUINO_NANO
U1, | 1 | LM358 | LM358
U2, | 1 | LM7805 | LM7805_TO220
ZX1, | 1 | 16PIN ZIF | 16Pin ZIF

## Schematic Diagram

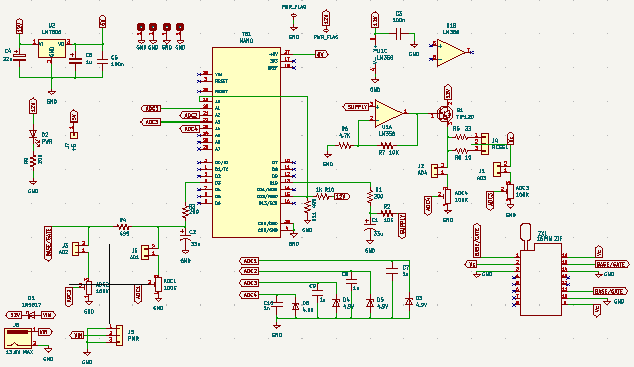
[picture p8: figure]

## Printed Circuit Board Layout

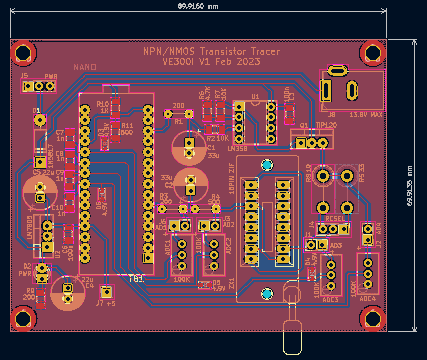
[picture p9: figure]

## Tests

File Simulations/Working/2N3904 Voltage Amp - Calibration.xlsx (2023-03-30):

 |  |  |  | Slope | Int
Vcontrol | Vin | Vout | Vin | 0.001030395536 | -0.07296102805
1000 | 0.98 | 0.772 | Vout (all) | 0.003386973157 | -3.690312939
1200 | 1.19 | 0.798 | Vout | 0.003426860207 | -3.755802275
1400 | 1.35 | 0.798
1700 | 1.67 | 1.59 | Vin | 3000
1800 | 1.75 | 1.59 | Vout | 6.524778344
1900 | 1.91 | 2.3
2000 | 1.99 | 2.39
2500 | 2.47 | 4.79
3000 | 3.03 | 7.18
3500 | 3.51 | 8.78
4000 | 4.06 | 10.3
4250 | 4.31 | 10.9
4600 | 4.68 | 11.1

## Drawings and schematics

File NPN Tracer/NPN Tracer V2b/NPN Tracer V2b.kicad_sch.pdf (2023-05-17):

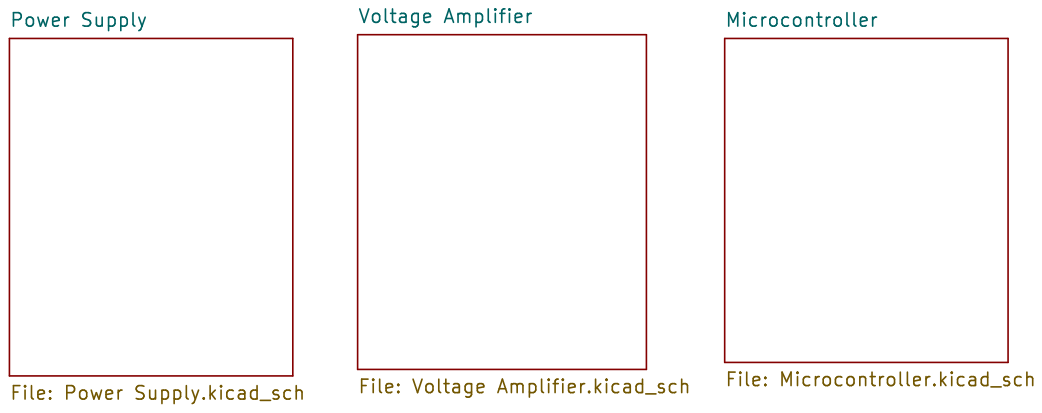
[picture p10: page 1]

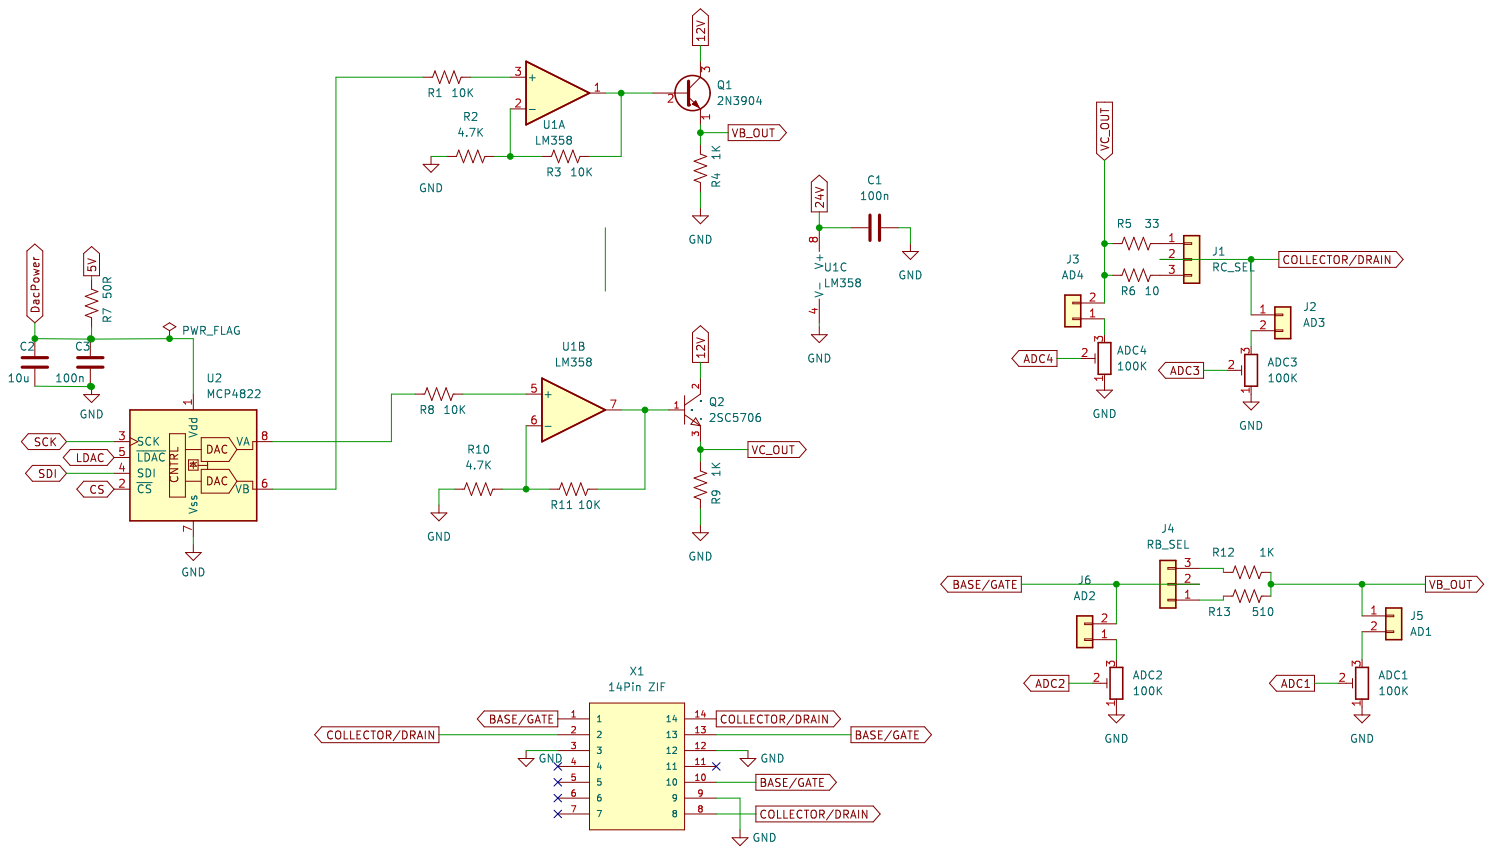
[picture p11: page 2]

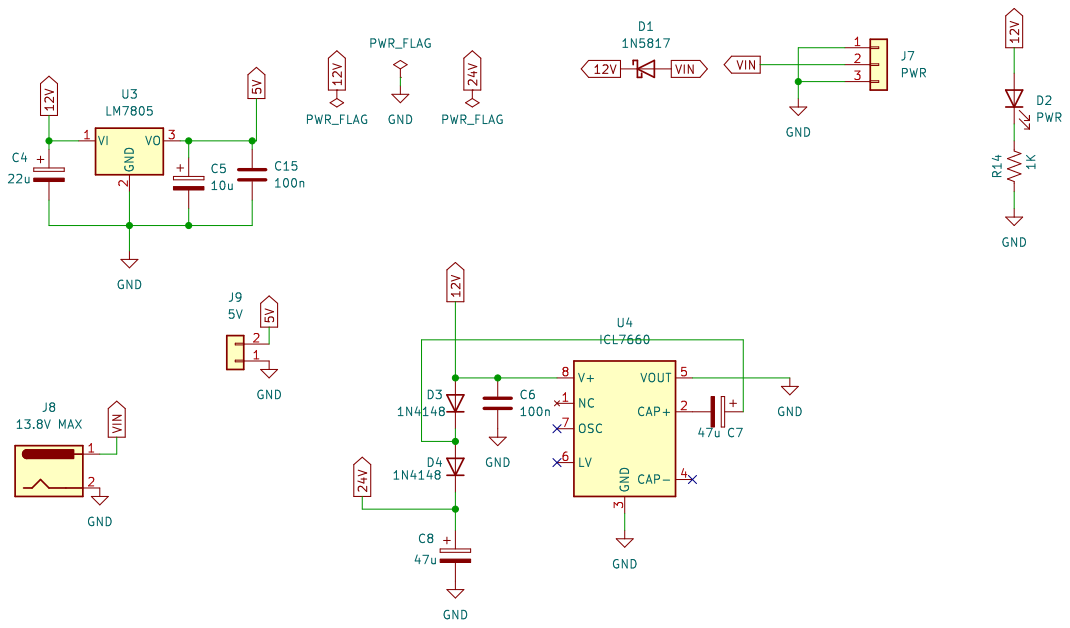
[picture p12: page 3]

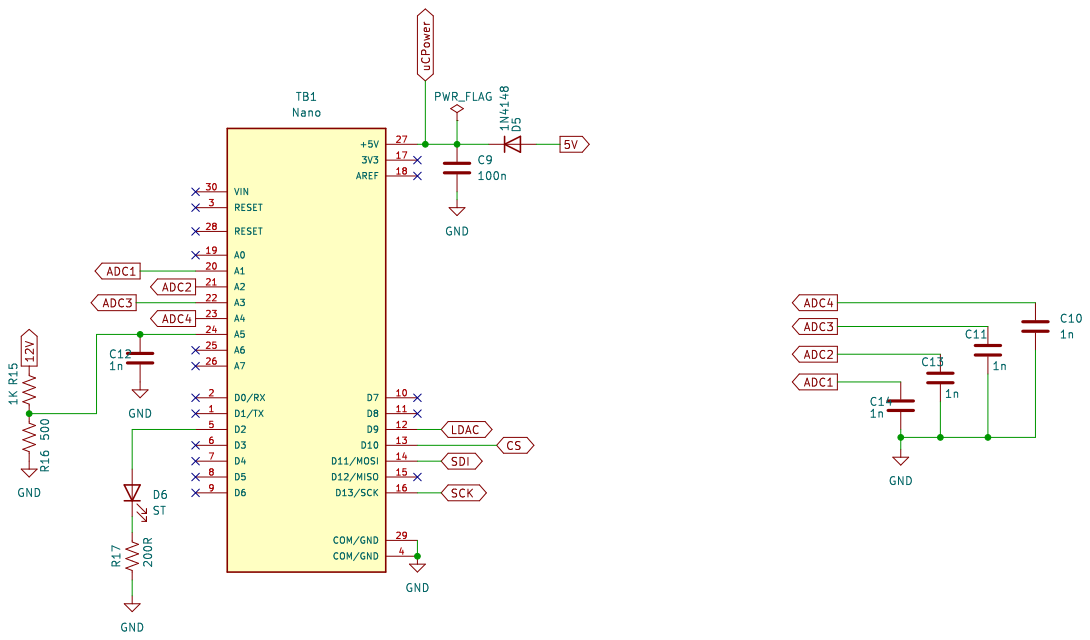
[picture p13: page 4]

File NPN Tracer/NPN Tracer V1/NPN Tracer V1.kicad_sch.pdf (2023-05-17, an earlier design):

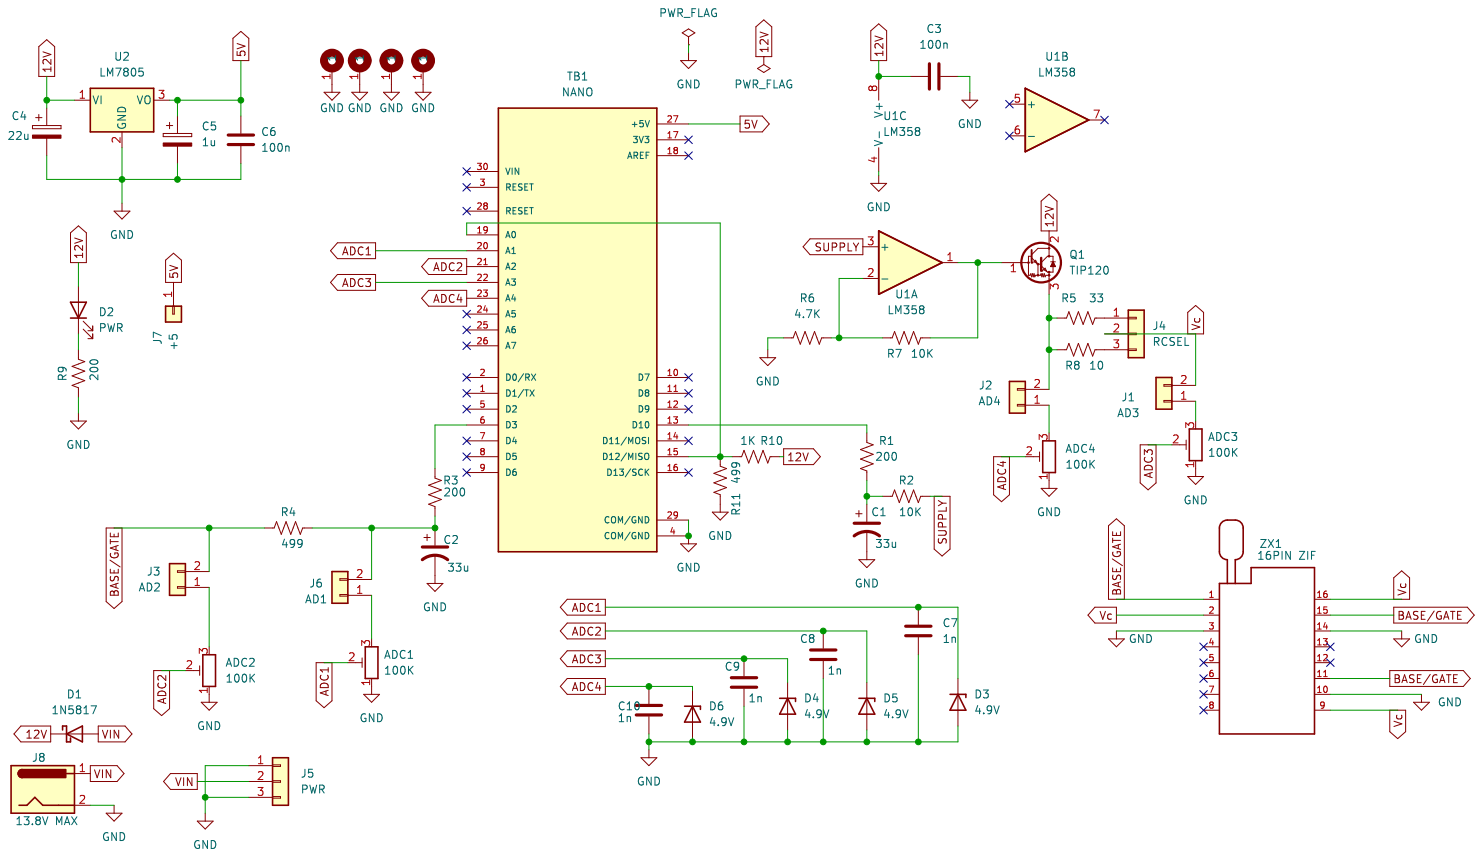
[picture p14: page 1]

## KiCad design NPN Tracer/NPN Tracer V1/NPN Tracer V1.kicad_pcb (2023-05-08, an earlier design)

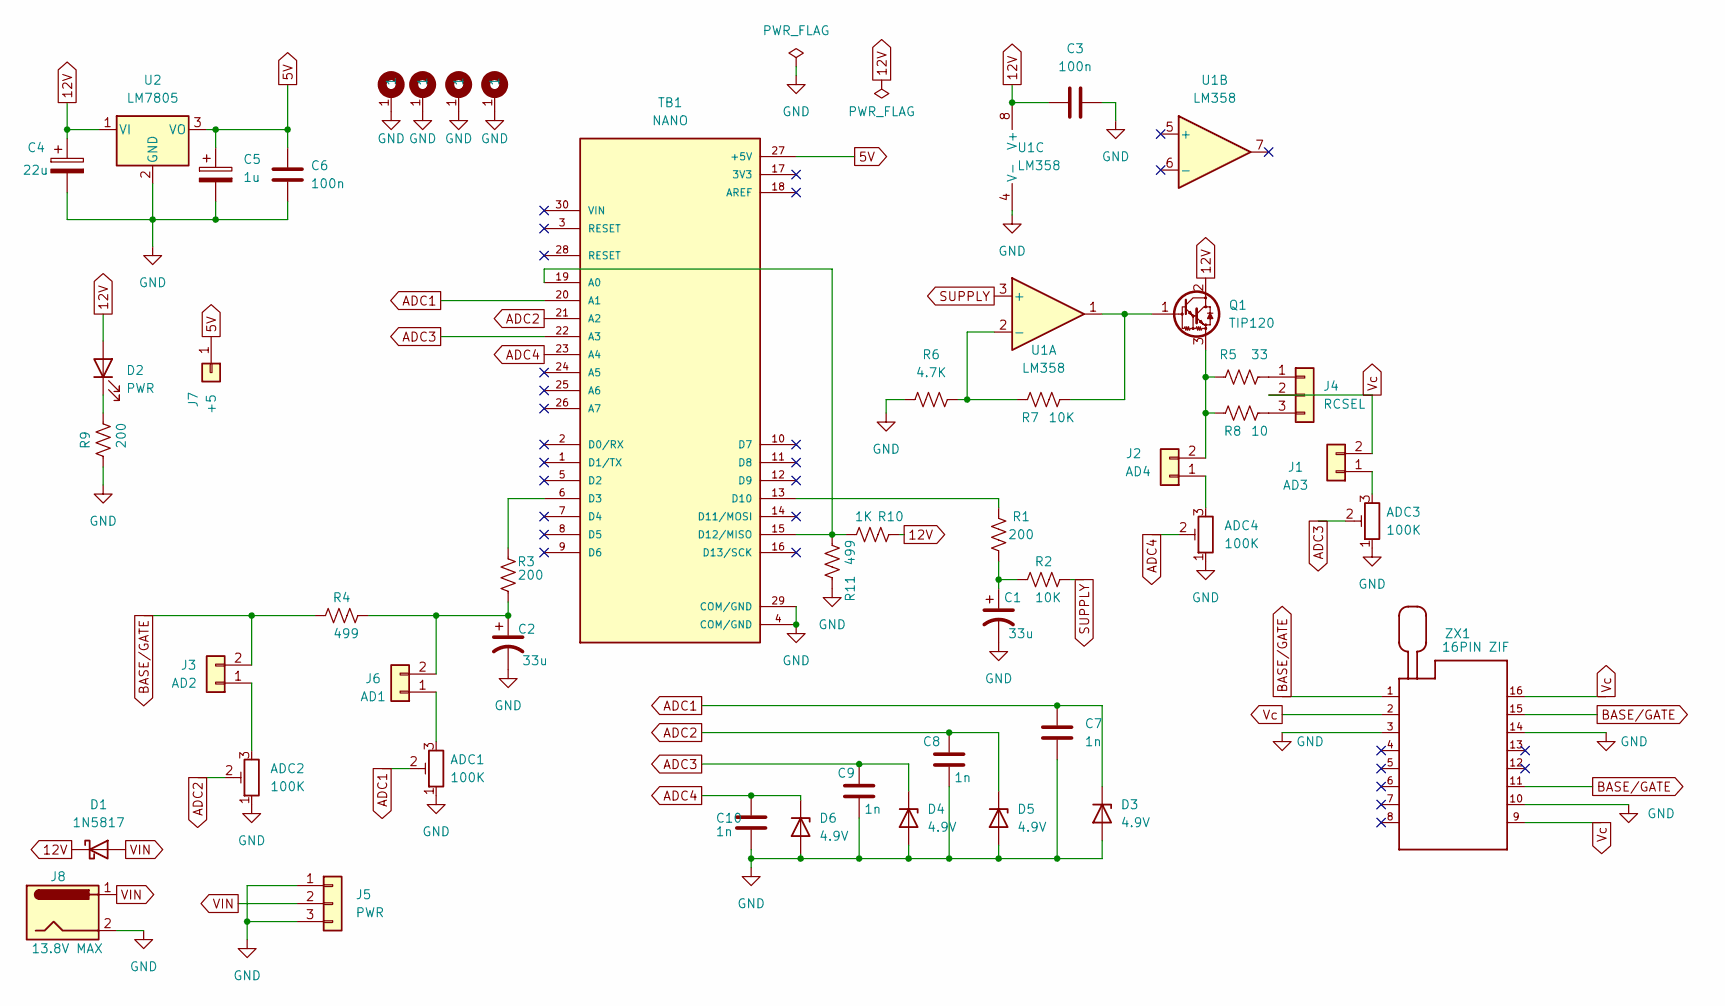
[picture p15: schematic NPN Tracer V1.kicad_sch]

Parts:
ADC1, ADC2, ADC3, ADC4: 100K; Potentiometer_Bourns_3296W_Vertical
C1, C2: 33u; CP_Radial_D8.0mm_P2.50mm
C3: 100n; C_1206_3216Metric_Pad1.33x1.80mm_HandSolder
C4: 22u; CP_Radial_D8.0mm_P2.50mm
C5: 1u; CP_Radial_D8.0mm_P2.50mm
C6: 100n; C_1206_3216Metric
C7, C8, C9, C10: 1n; C_1206_3216Metric
D1: 1N5817; D_DO-41_SOD81_P10.16mm_Horizontal
D2: PWR; LED_D3.0mm
D3, D4, D5, D6: 4.9V; D_SOD-323
H1, H2, H3, H4: MountingHole; MountingHole_3.2mm_M3_ISO7380_Pad_TopBottom
J1: AD3; PinHeader_1x02_P2.54mm_Vertical
J2: AD4; PinHeader_1x02_P2.54mm_Vertical
J3: AD2; PinHeader_1x02_P2.54mm_Vertical
J4: RCSEL; PinHeader_1x03_P2.54mm_Vertical
J5: PWR; PinHeader_1x03_P2.54mm_Vertical
J6: AD1; PinHeader_1x02_P2.54mm_Vertical
J7: +5; PinHeader_1x01_P2.54mm_Vertical
J8: 13.8V MAX; BarrelJack_GCT_DCJ200-10-A_Horizontal
Q1: TIP120; TO-220-3_Vertical
R1, R3: 200; R_Axial_DIN0204_L3.6mm_D1.6mm_P5.08mm_Vertical
R2, R7: 10K; R_1206_3216Metric_Pad1.30x1.75mm_HandSolder
R4: 499; R_Axial_DIN0204_L3.6mm_D1.6mm_P5.08mm_Vertical
R5: 33; R_Axial_DIN0516_L15.5mm_D5.0mm_P7.62mm_Vertical
R6: 4.7K; R_1206_3216Metric_Pad1.30x1.75mm_HandSolder
R8: 10; R_Axial_DIN0516_L15.5mm_D5.0mm_P7.62mm_Vertical
R9: 200; R_1206_3216Metric_Pad1.30x1.75mm_HandSolder
R10: 1K; R_1206_3216Metric_Pad1.30x1.75mm_HandSolder
R11: 499; R_1206_3216Metric_Pad1.30x1.75mm_HandSolder
TB1: NANO; SHIELD_ARDUINO_NANO
U1: LM358; DIP-8_W7.62mm_Socket
U2: LM7805; TO-220-3_Vertical
ZX1: 16PIN ZIF; 16Pin ZIF; MPN 216-3340-00-0602J

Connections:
5V: C5.1, C6.1, J7.1, TB1.27 (+5V), U2.3 (VO)
12V: C3.1, C4.1, D1.1 (K), D2.2 (A), Q1.2 (C), R10.2, U1.8 (V+), U2.1 (VI)
ADC1: ADC1.2, C7.1, D3.1 (K), TB1.20 (A1)
ADC2: ADC2.2, C8.1, D5.1 (K), TB1.21 (A2)
ADC3: ADC3.2, C9.1, D4.1 (K), TB1.22 (A3)
ADC4: ADC4.2, C10.1, D6.1 (K), TB1.23 (A4)
BASE/GATE: J3.2, R4.1, ZX1.1, ZX1.11, ZX1.15
GND: ADC1.1, ADC2.1, ADC3.1, ADC4.1, C1.2, C2.2, C3.2, C4.2, C5.2, C6.2, C7.2, C8.2, C9.2, C10.2, D3.2 (A), D4.2 (A), D5.2 (A), D6.2 (A), H1.1, H2.1, H3.1, H4.1, J5.1, J5.3, J8.2, R6.1, R9.1, R11.2, TB1.4 (COM/GND), TB1.29 (COM/GND), U1.4 (V-), U2.2 (GND), ZX1.3, ZX1.10, ZX1.14
unnamed: ADC1.3, J6.1
unnamed: ADC2.3, J3.1
unnamed: ADC3.3, J1.1
unnamed: ADC4.3, J2.1
unnamed: C1.1, R1.1, R2.1
unnamed: C2.1, J6.2, R3.1, R4.2
unnamed: D2.1 (K), R9.2
unnamed: J2.2, Q1.3 (E), R5.1, R8.1
unnamed: J4.1, R5.2
unnamed: J4.3, R8.2
unnamed: Q1.1 (B), R7.2, U1.1
unnamed: R1.2, TB1.13 (D10)
unnamed: R3.2, TB1.6 (D3)
unnamed: R6.2, R7.1, U1.2 (-)
unnamed: R10.1, R11.1, TB1.15 (D12/MISO), TB1.19 (A0)
SUPPLY: R2.2, U1.3 (+)
VIN: D1.2 (A), J5.2, J8.1
Vc: J1.2, J4.2, ZX1.2, ZX1.9, ZX1.16

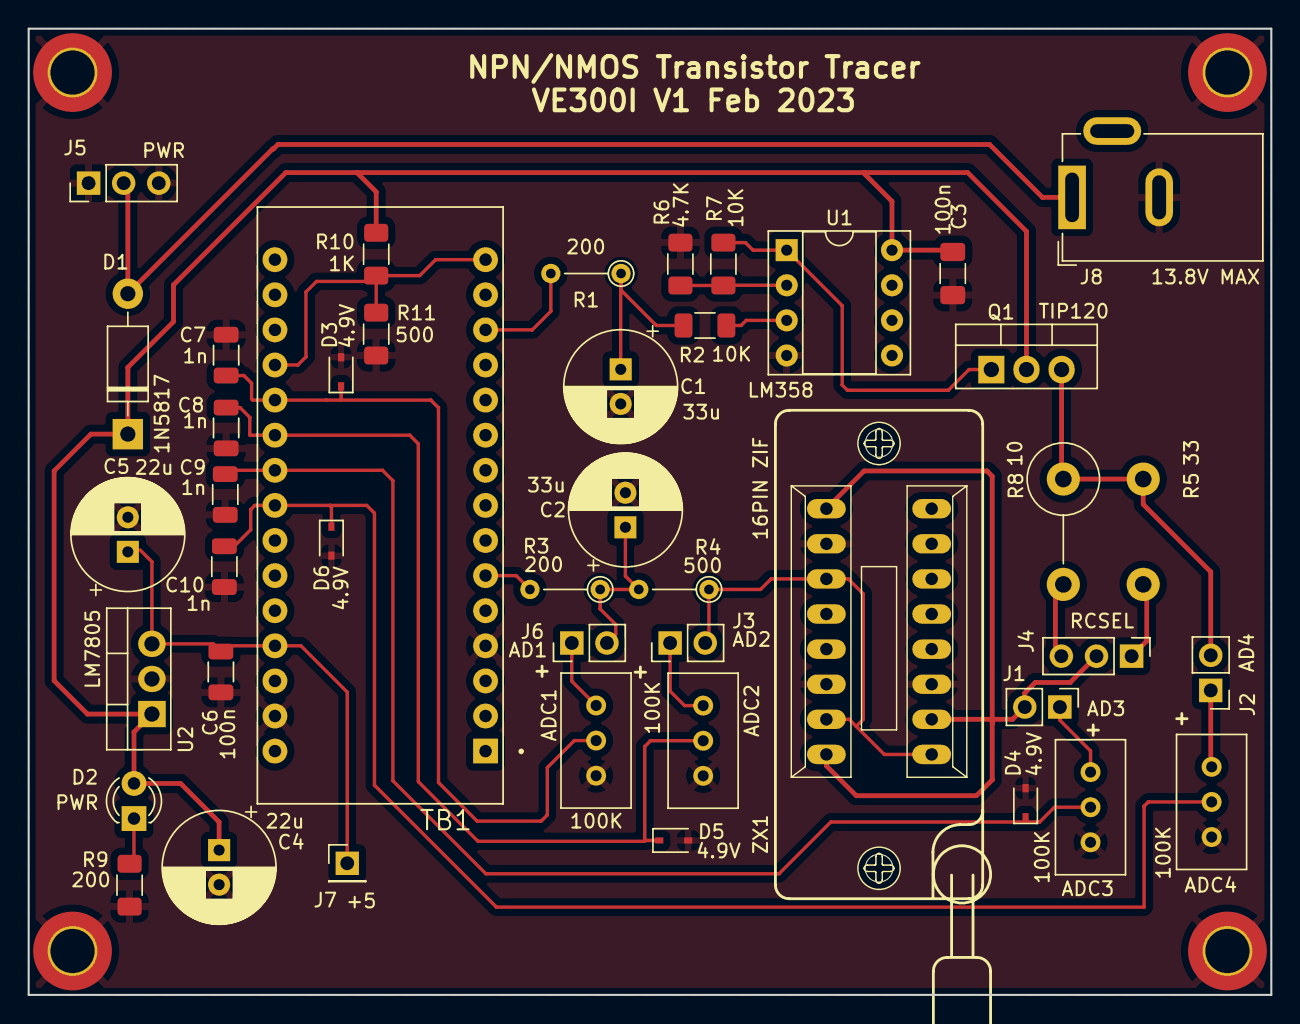
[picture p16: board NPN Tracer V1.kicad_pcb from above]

Board: 2 copper layers, 89.9 x 69.9 mm, 48 parts (1 on the bottom side), 26 nets.

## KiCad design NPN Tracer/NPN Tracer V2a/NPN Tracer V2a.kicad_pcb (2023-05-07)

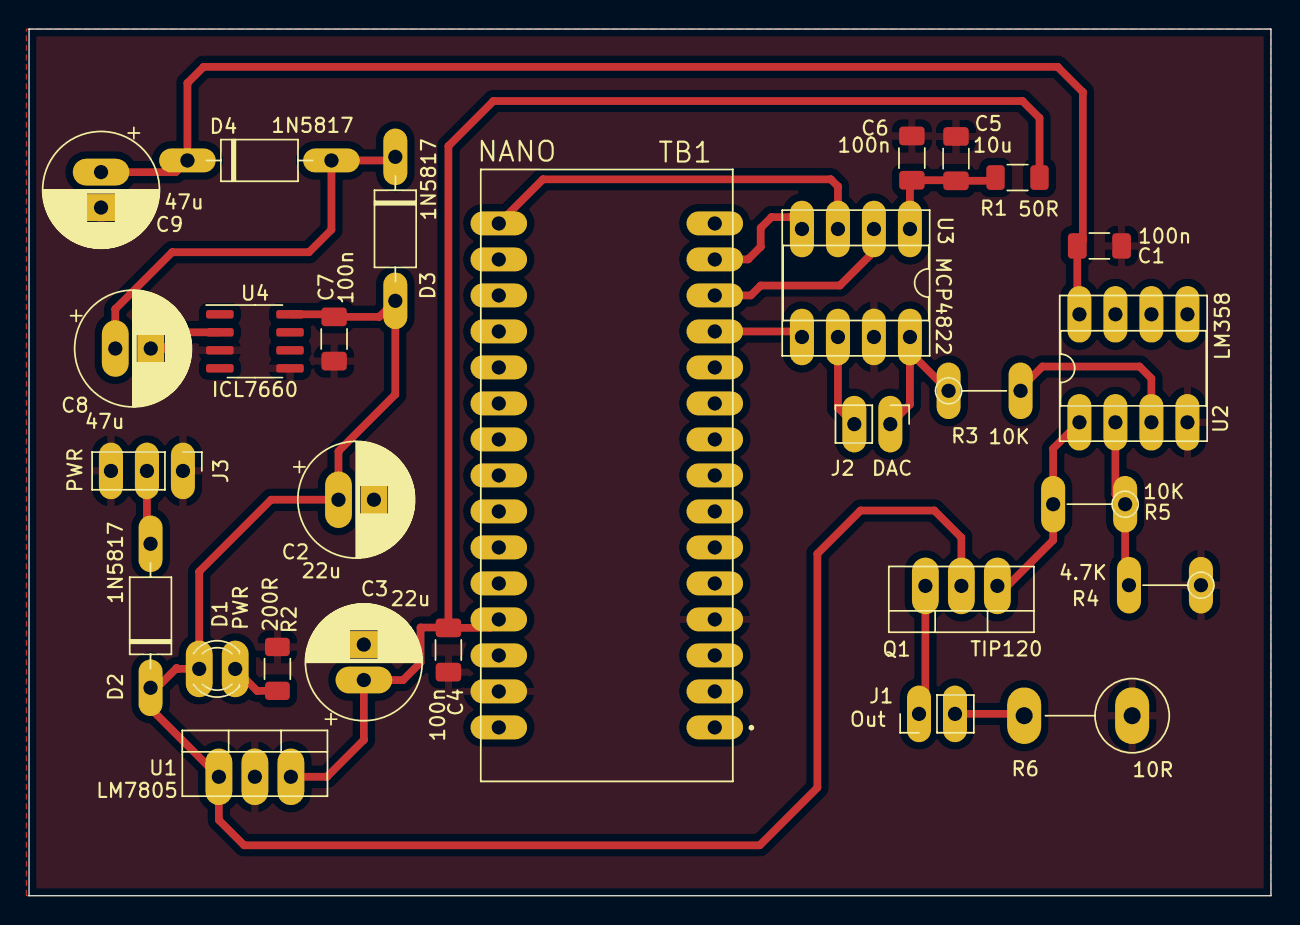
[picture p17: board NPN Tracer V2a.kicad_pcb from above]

Board: 2 copper layers, 87.6 x 61.2 mm, 28 parts (0 on the bottom side), 20 nets.

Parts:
C1, C4, C6, C7: 100n; C_1206_3216Metric_Pad1.33x1.80mm_HandSolder
C2, C3: 22u; CP_Radial_D8.0mm_P2.50mm
C5: 10u; C_1206_3216Metric_Pad1.33x1.80mm_HandSolder
C8, C9: 47u; CP_Radial_D8.0mm_P2.50mm
D1: PWR; LED_D3.0mm
D2, D3, D4: 1N5817; D_DO-41_SOD81_P10.16mm_Horizontal
J1: Out; PinHeader_1x02_P2.54mm_Vertical
J2: DAC; PinHeader_1x02_P2.54mm_Vertical
J3: PWR; PinHeader_1x03_P2.54mm_Vertical
Q1: TIP120; TO-220-3_Vertical
R1: 50R; R_1206_3216Metric_Pad1.30x1.75mm_HandSolder
R2: 200R; R_1206_3216Metric_Pad1.30x1.75mm_HandSolder
R3, R5: 10K; R_Axial_DIN0204_L3.6mm_D1.6mm_P5.08mm_Vertical
R4: 4.7K; R_Axial_DIN0204_L3.6mm_D1.6mm_P5.08mm_Vertical
R6: 10R; R_Axial_DIN0516_L15.5mm_D5.0mm_P7.62mm_Vertical
TB1: NANO; SHIELD_ARDUINO_NANO
U1: LM7805; TO-220-3_Vertical
U2: LM358; DIP-8_W7.62mm_Socket
U3: MCP4822; DIP-8_W7.62mm_Socket
U4: ICL7660; SOIC-8_3.9x4.9mm_P1.27mm

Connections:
5V: C3.1, C4.2, R1.2, TB1.27 (+5V), U1.3 (VO)
12V: C2.1, C7.2, D1.2 (A), D2.1 (K), D3.2 (A), Q1.2 (C), U1.1 (VI), U4.8 (V+)
24V: C1.1, C9.1, D4.1 (K), U2.8 (V+)
GND: C1.2, C2.2, C3.2, C4.1, C5.1, C6.1, C7.1, C9.2, J3.1, J3.3, R2.1, R4.1, R6.1, TB1.4 (COM/GND), TB1.29 (COM/GND), U1.2 (GND), U2.4 (V-), U3.7 (Vss), U4.3 (GND), U4.5 (VOUT)
unnamed: C5.2, C6.2, R1.1, U3.1 (Vdd)
unnamed: C8.1, D3.1 (K), D4.2 (A)
unnamed: C8.2, U4.2 (CAP+)
unnamed: D1.1 (K), R2.2
unnamed: J1.1, Q1.3 (E)
unnamed: J1.2, R6.2
unnamed: J2.1, R3.1, U3.8 (VA)
unnamed: J2.2, U3.6 (VB)
unnamed: Q1.1 (B), R5.2, U2.1
unnamed: R3.2, U2.3 (+)
unnamed: R4.2, R5.1, U2.2 (-)
unnamed: TB1.12 (D9), U3.5 (~LDAC)
unnamed: TB1.13 (D10), U3.2 (~CS)
unnamed: TB1.14 (D11/MOSI), U3.4 (SDI)
unnamed: TB1.16 (D13/SCK), U3.3 (SCK)
VIN: D2.2 (A), J3.2

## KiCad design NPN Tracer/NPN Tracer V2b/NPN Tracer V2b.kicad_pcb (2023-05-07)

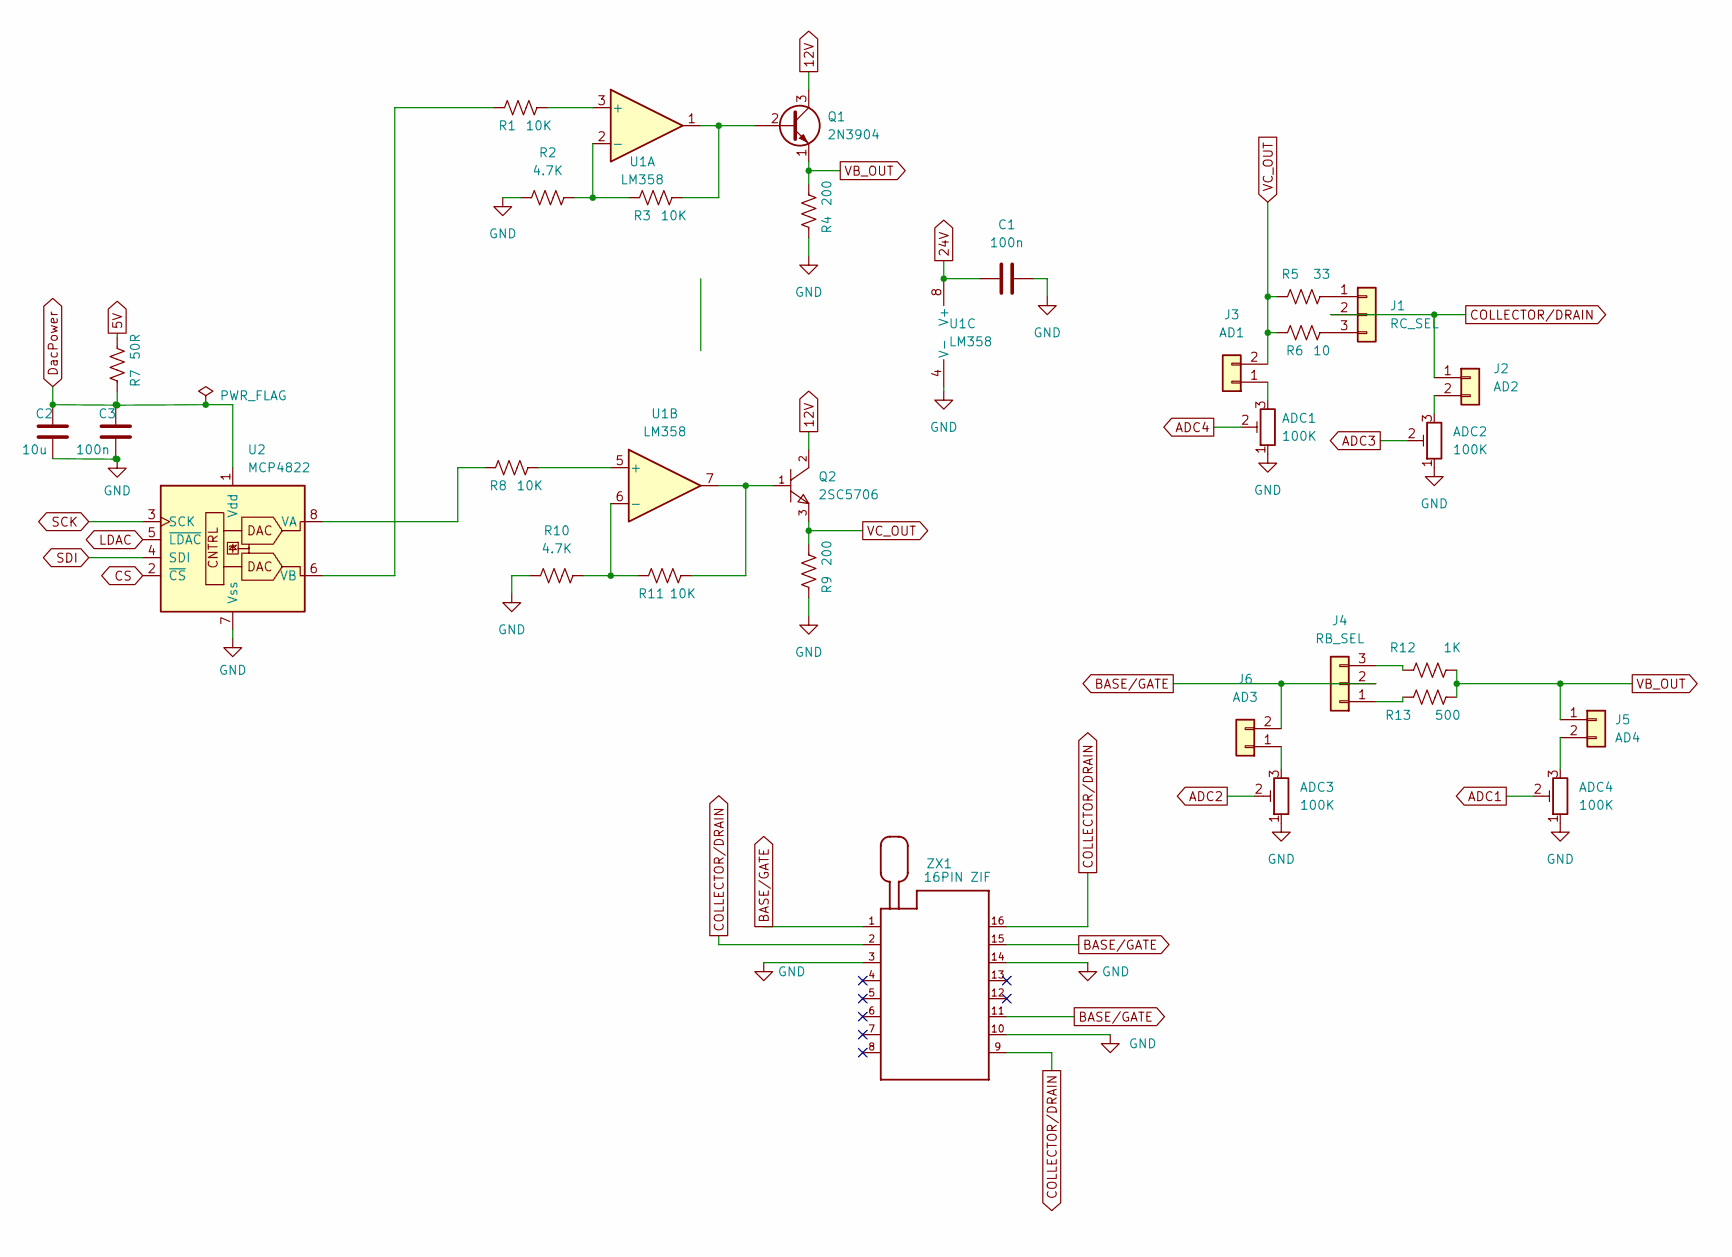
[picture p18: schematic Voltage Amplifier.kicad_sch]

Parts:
ADC1, ADC2, ADC3, ADC4: 100K; Potentiometer_Bourns_3296W_Vertical
C1, C3: 100n; C_1206_3216Metric
C2: 10u; C_1206_3216Metric
J1: RC_SEL; PinHeader_1x03_P2.54mm_Vertical
J2: AD2; PinHeader_1x02_P2.54mm_Vertical
J3: AD1; PinHeader_1x02_P2.54mm_Vertical
J4: RB_SEL; PinHeader_1x03_P2.54mm_Vertical
J5: AD4; PinHeader_1x02_P2.54mm_Vertical
J6: AD3; PinHeader_1x02_P2.54mm_Vertical
Q1: 2N3904; TO-92_Inline_Wide
Q2: 2SC5706
R1, R3, R8, R11: 10K; R_1206_3216Metric
R2, R10: 4.7K; R_1206_3216Metric
R4, R9: 200; R_1206_3216Metric
R5: 33; R_Axial_DIN0411_L9.9mm_D3.6mm_P7.62mm_Vertical
R6: 10; R_Axial_DIN0411_L9.9mm_D3.6mm_P7.62mm_Vertical
R7: 50R; R_1206_3216Metric
R12: 1K; R_1206_3216Metric
R13: 500; R_1206_3216Metric
U1: LM358; DIP-8_W7.62mm_Socket
U2: MCP4822; SOIC-8_3.9x4.9mm_P1.27mm
ZX1: 16PIN ZIF; 16Pin ZIF; MPN 216-3340-00-0602J

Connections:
5V: R7.2; also elsewhere on the board
12V: Q1.3 (C), Q2.2 (C); also elsewhere on the board
24V: C1.1, U1.8 (V+); also elsewhere on the board
ADC1: ADC4.2; also elsewhere on the board
ADC2: ADC3.2; also elsewhere on the board
ADC3: ADC2.2; also elsewhere on the board
ADC4: ADC1.2; also elsewhere on the board
BASE/GATE: J4.2, J6.2, ZX1.1, ZX1.11, ZX1.15
COLLECTOR/DRAIN: J1.2, J2.1, ZX1.2, ZX1.9, ZX1.16
CS: U2.2 (~CS); also elsewhere on the board
DacPower: C2.2, C3.2, R7.1, U2.1 (Vdd)
GND: ADC1.1, ADC2.1, ADC3.1, ADC4.1, C1.2, C2.1, C3.1, R2.1, R4.1, R9.1, R10.1, U1.4 (V-), U2.7 (Vss), ZX1.3, ZX1.10, ZX1.14; also elsewhere on the board
LDAC: U2.5 (~LDAC); also elsewhere on the board
unnamed: ADC1.3, J3.1
unnamed: ADC2.3, J2.2
unnamed: ADC3.3, J6.1
unnamed: ADC4.3, J5.2
unnamed: J1.1, R5.2
unnamed: J1.3, R6.2
unnamed: J4.1, R13.1
unnamed: J4.3, R12.1
unnamed: Q1.2 (B), R3.2, U1.1
unnamed: Q2.1 (B), R11.2, U1.7
unnamed: R1.1, U2.6 (VB)
unnamed: R1.2, U1.3 (+)
unnamed: R2.2, R3.1, U1.2 (-)
unnamed: R8.1, U2.8 (VA)
unnamed: R8.2, U1.5 (+)
unnamed: R10.2, R11.1, U1.6 (-)
SCK: U2.3 (SCK); also elsewhere on the board
SDI: U2.4 (SDI); also elsewhere on the board
VB_OUT: J5.1, Q1.1 (E), R4.2, R12.2, R13.2
VC_OUT: J3.2, Q2.3 (E), R5.1, R6.1, R9.2

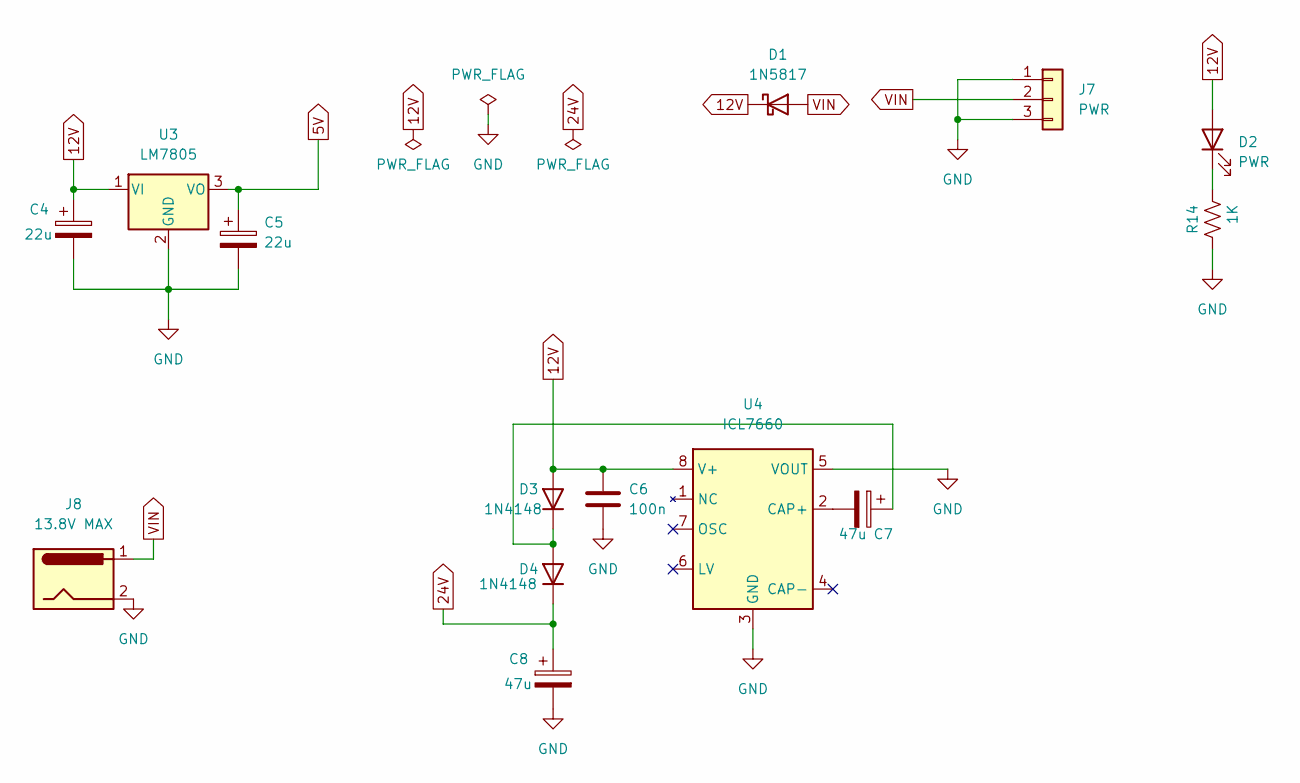
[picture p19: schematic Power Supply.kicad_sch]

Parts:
C4, C5: 22u; CP_Radial_D8.0mm_P2.50mm
C6: 100n; C_1206_3216Metric
C7, C8: 47u; CP_Radial_D8.0mm_P2.50mm
D1: 1N5817; D_DO-41_SOD81_P10.16mm_Horizontal
D2: PWR; LED_D3.0mm
D3, D4: 1N4148; D_MiniMELF
J7: PWR; PinHeader_1x03_P2.54mm_Vertical
J8: 13.8V MAX; BarrelJack_GCT_DCJ200-10-A_Horizontal
R14: 1K; R_1206_3216Metric
U3: LM7805; TO-220-3_Vertical
U4: ICL7660; SOIC-8_3.9x4.9mm_P1.27mm

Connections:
5V: C5.1, U3.3 (VO); also elsewhere on the board
12V: C4.1, C6.2, D1.1 (K), D2.2 (A), D3.2 (A), U3.1 (VI), U4.8 (V+); also elsewhere on the board
24V: C8.1, D4.1 (K); also elsewhere on the board
GND: C4.2, C5.2, C6.1, C8.2, J7.1, J7.3, J8.2, R14.1, U3.2 (GND), U4.3 (GND), U4.5 (VOUT); also elsewhere on the board
unnamed: C7.1, D3.1 (K), D4.2 (A)
unnamed: C7.2, U4.2 (CAP+)
unnamed: D2.1 (K), R14.2
VIN: D1.2 (A), J7.2, J8.1

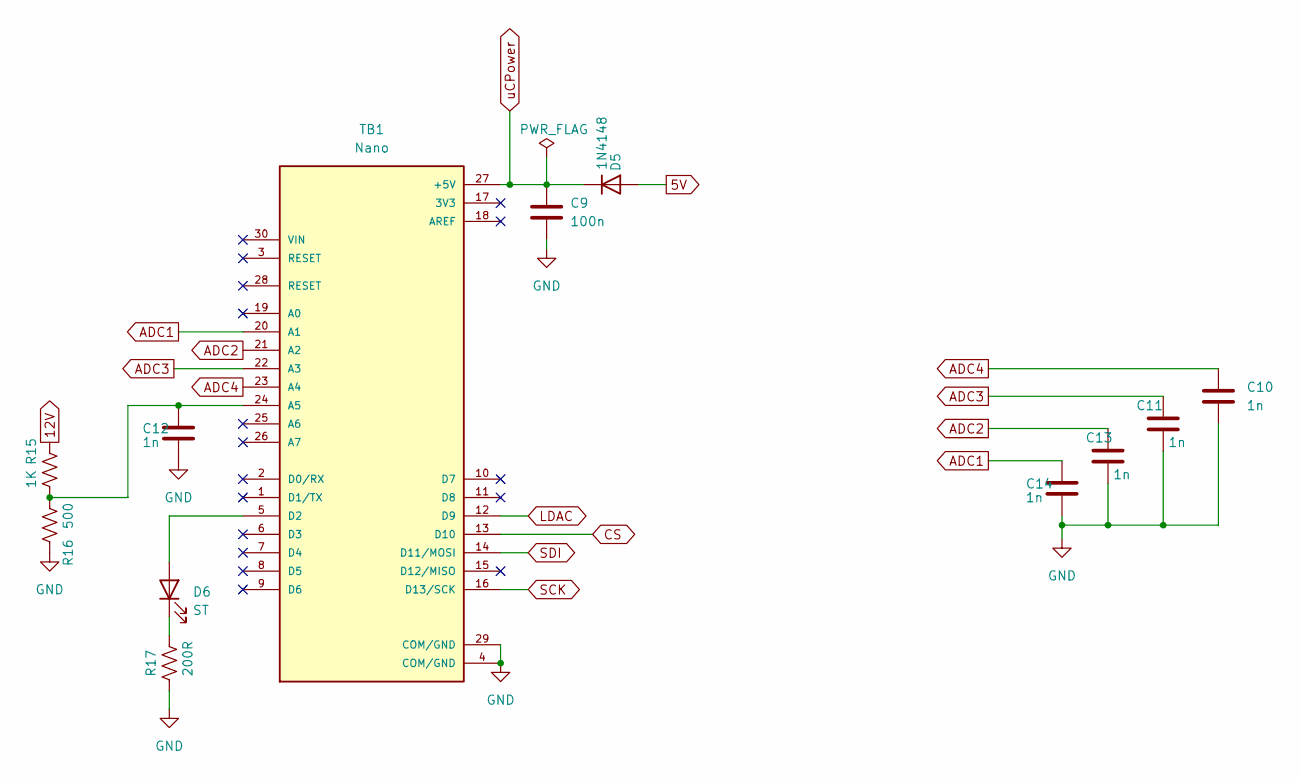
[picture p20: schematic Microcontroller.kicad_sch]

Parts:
C9: 100n; C_1206_3216Metric
C10, C11, C12, C13, C14: 1n; C_1206_3216Metric
D5: 1N4148; D_MiniMELF
D6: ST; LED_D3.0mm
R15: 1K; R_1206_3216Metric
R16: 500; R_1206_3216Metric
R17: 200R; R_1206_3216Metric
TB1: Nano; SHIELD_ARDUINO_NANO

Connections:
5V: D5.2 (A); also elsewhere on the board
12V: R15.2; also elsewhere on the board
ADC1: C14.1, TB1.20 (A1); also elsewhere on the board
ADC2: C13.1, TB1.21 (A2); also elsewhere on the board
ADC3: C11.1, TB1.22 (A3); also elsewhere on the board
ADC4: C10.1, TB1.23 (A4); also elsewhere on the board
CS: TB1.13 (D10); also elsewhere on the board
GND: C9.2, C10.2, C11.2, C12.2, C13.2, C14.2, R16.2, R17.1, TB1.4 (COM/GND), TB1.29 (COM/GND); also elsewhere on the board
LDAC: TB1.12 (D9); also elsewhere on the board
unnamed: C12.1, R15.1, R16.1, TB1.24 (A5)
unnamed: D6.1 (K), R17.2
unnamed: D6.2 (A), TB1.5 (D2)
SCK: TB1.16 (D13/SCK); also elsewhere on the board
SDI: TB1.14 (D11/MOSI); also elsewhere on the board
uCPower: C9.1, D5.1 (K), TB1.27 (+5V)

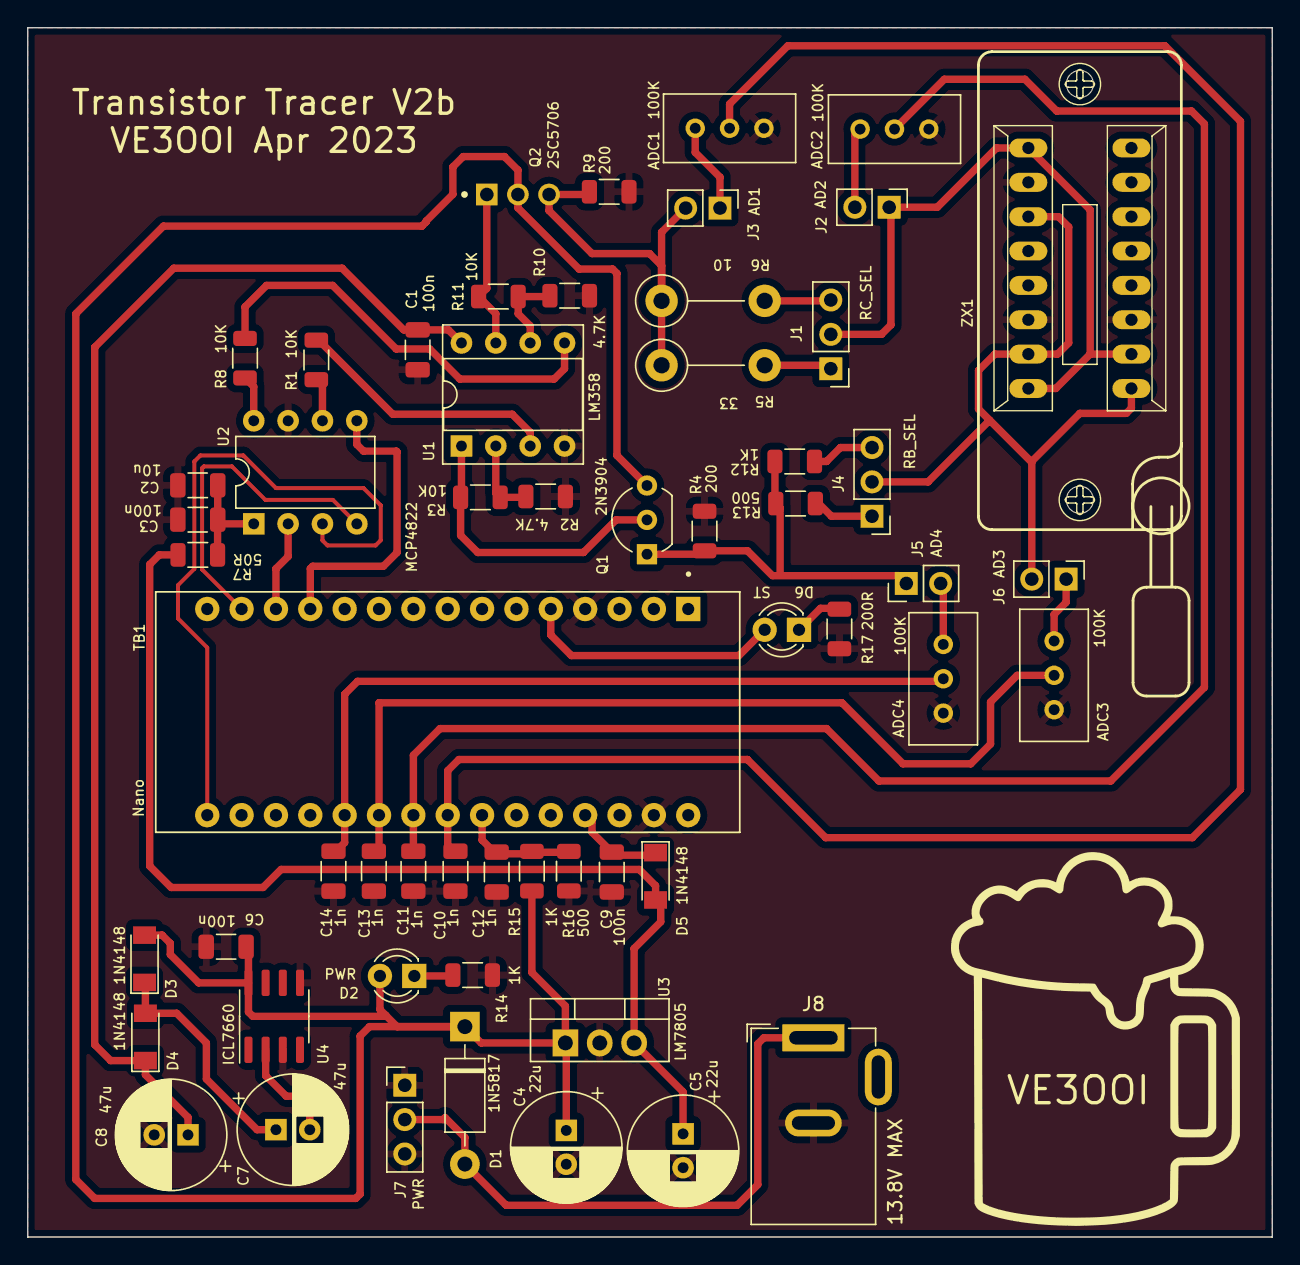
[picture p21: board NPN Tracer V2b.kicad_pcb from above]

Board: 2 copper layers, 92.0 x 89.4 mm, 57 parts (0 on the bottom side), 41 nets.

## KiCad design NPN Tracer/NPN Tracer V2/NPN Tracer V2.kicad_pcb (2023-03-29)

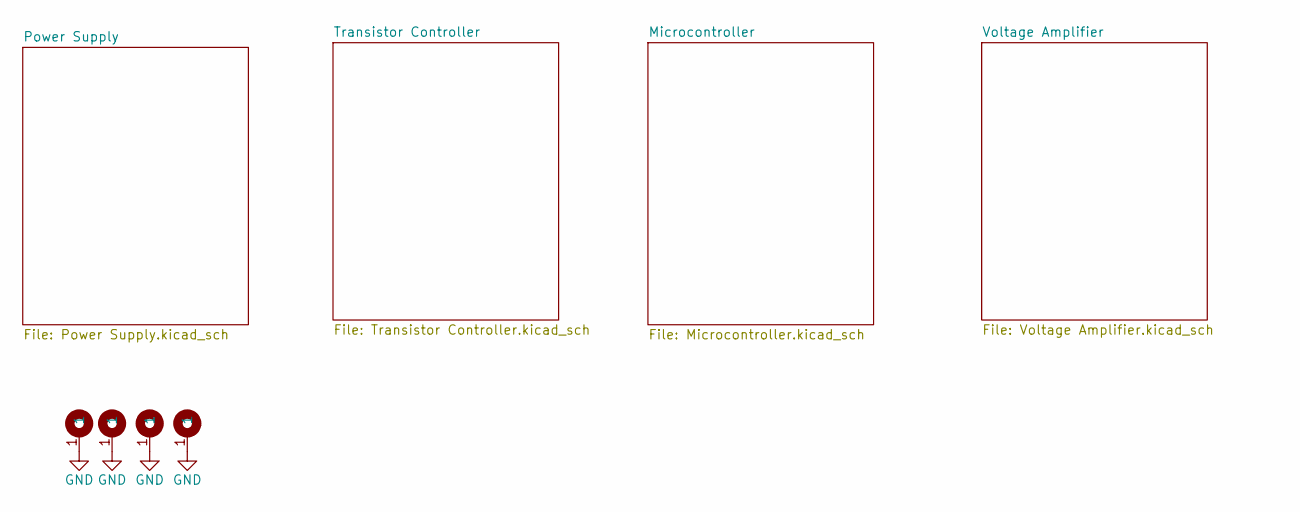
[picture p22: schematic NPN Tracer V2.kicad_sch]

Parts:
H1, H2, H3, H4: MountingHole; MountingHole_3.2mm_M3_ISO7380_Pad_TopBottom

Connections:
GND: H1.1, H2.1, H3.1, H4.1; also elsewhere on the board

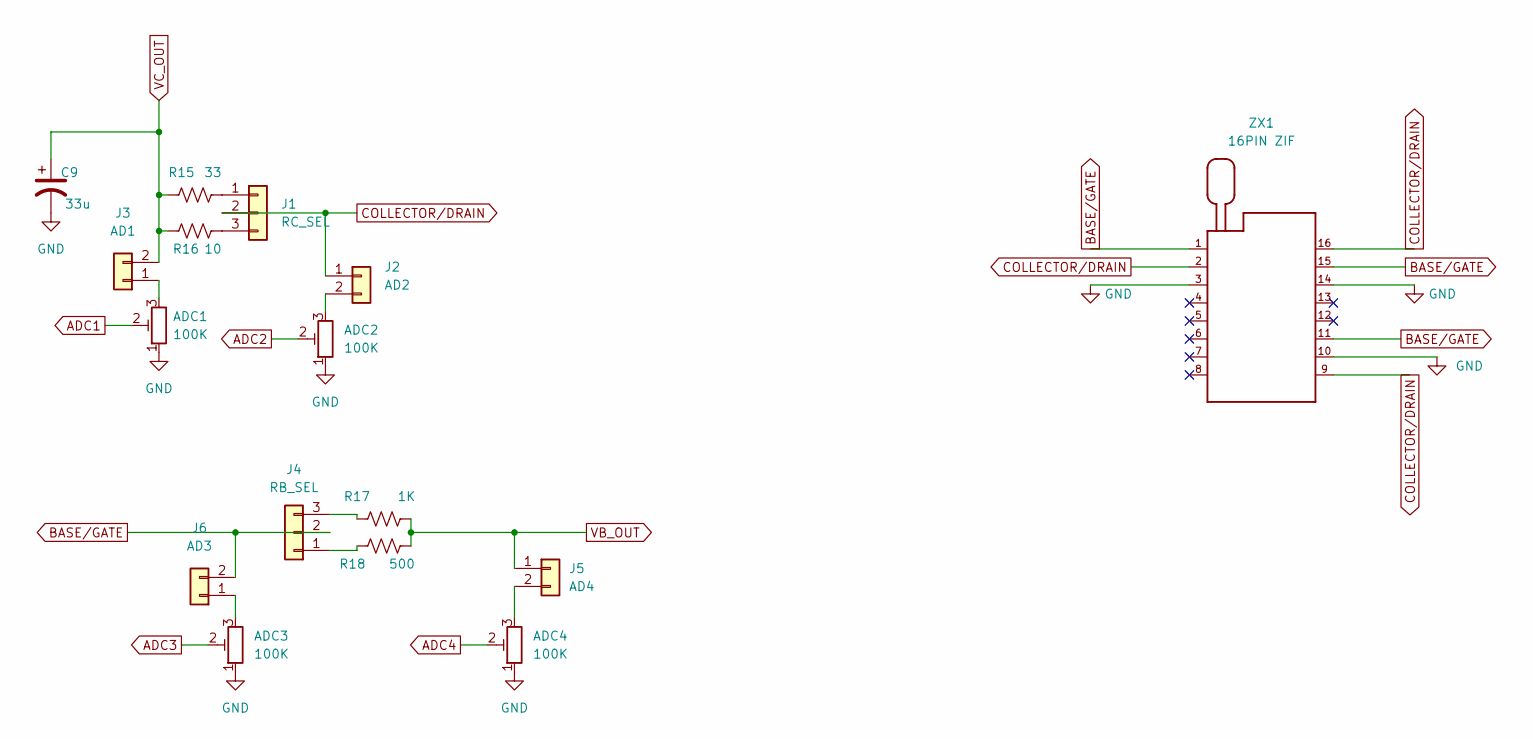
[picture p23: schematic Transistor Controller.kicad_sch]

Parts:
ADC1, ADC2, ADC3, ADC4: 100K; Potentiometer_Bourns_3296W_Vertical
C9: 33u; CP_Radial_D8.0mm_P2.50mm
J1: RC_SEL; PinHeader_1x03_P2.54mm_Vertical
J2: AD2; PinHeader_1x02_P2.54mm_Vertical
J3: AD1; PinHeader_1x02_P2.54mm_Vertical
J4: RB_SEL; PinHeader_1x03_P2.54mm_Vertical
J5: AD4; PinHeader_1x02_P2.54mm_Vertical
J6: AD3; PinHeader_1x02_P2.54mm_Vertical
R15: 33; R_Axial_DIN0411_L9.9mm_D3.6mm_P7.62mm_Vertical
R16: 10; R_Axial_DIN0411_L9.9mm_D3.6mm_P7.62mm_Vertical
R17: 1K; R_1206_3216Metric
R18: 500; R_1206_3216Metric
ZX1: 16PIN ZIF; 16Pin ZIF; MPN 216-3340-00-0602J

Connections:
ADC1: ADC1.2; also elsewhere on the board
ADC2: ADC2.2; also elsewhere on the board
ADC3: ADC3.2; also elsewhere on the board
ADC4: ADC4.2; also elsewhere on the board
BASE/GATE: J4.2, J6.2, ZX1.1, ZX1.11, ZX1.15
COLLECTOR/DRAIN: J1.2, J2.1, ZX1.2, ZX1.9, ZX1.16
GND: ADC1.1, ADC2.1, ADC3.1, ADC4.1, C9.2, ZX1.3, ZX1.10, ZX1.14; also elsewhere on the board
unnamed: ADC1.3, J3.1
unnamed: ADC2.3, J2.2
unnamed: ADC3.3, J6.1
unnamed: ADC4.3, J5.2
unnamed: J1.1, R15.2
unnamed: J1.3, R16.2
unnamed: J4.1, R18.1
unnamed: J4.3, R17.1
VB_OUT: J5.1, R17.2, R18.2; also elsewhere on the board
VC_OUT: C9.1, J3.2, R15.1, R16.1; also elsewhere on the board

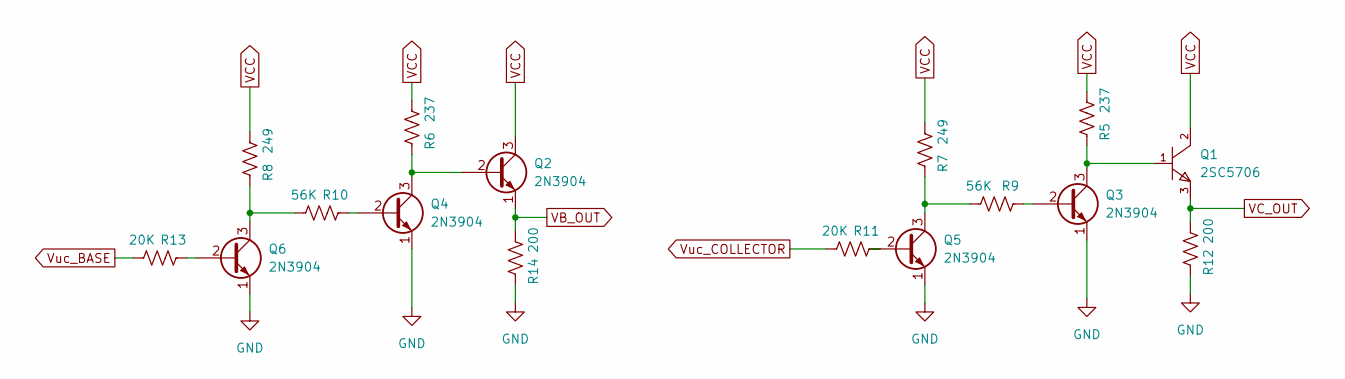
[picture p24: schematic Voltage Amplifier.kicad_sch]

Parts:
Q1: 2SC5706
Q2, Q3, Q4, Q5, Q6: 2N3904; TO-92_Inline
R5, R6: 237; R_1206_3216Metric
R7, R8: 249; R_1206_3216Metric
R9, R10: 56K; R_1206_3216Metric
R11, R13: 20K; R_1206_3216Metric
R12, R14: 200; R_1206_3216Metric

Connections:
GND: Q3.1 (E), Q4.1 (E), Q5.1 (E), Q6.1 (E), R12.1, R14.1; also elsewhere on the board
unnamed: Q1.1 (B), Q3.3 (C), R5.1
unnamed: Q2.2 (B), Q4.3 (C), R6.1
unnamed: Q3.2 (B), R9.1
unnamed: Q4.2 (B), R10.1
unnamed: Q5.2 (B), R11.1
unnamed: Q5.3 (C), R7.1, R9.2
unnamed: Q6.2 (B), R13.1
unnamed: Q6.3 (C), R8.1, R10.2
VB_OUT: Q2.1 (E), R14.2; also elsewhere on the board
VCC: Q1.2 (C), Q2.3 (C), R5.2, R6.2, R7.2, R8.2; also elsewhere on the board
VC_OUT: Q1.3 (E), R12.2; also elsewhere on the board
Vuc_BASE: R13.2; also elsewhere on the board
Vuc_COLLECTOR: R11.2; also elsewhere on the board

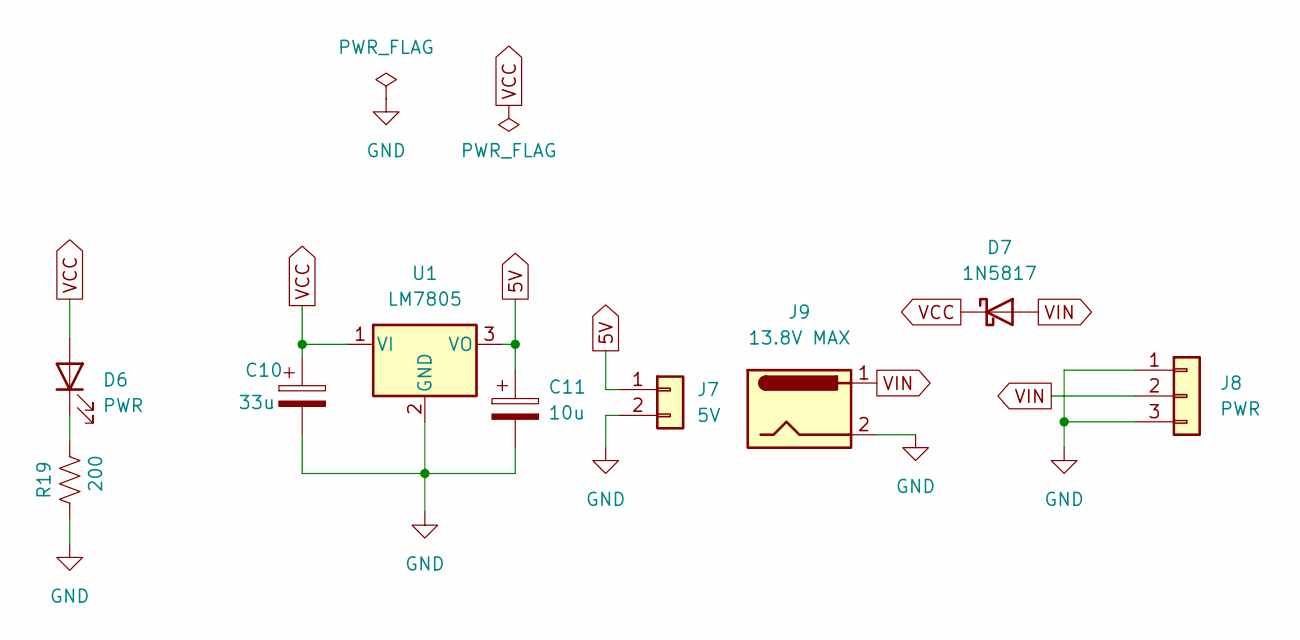
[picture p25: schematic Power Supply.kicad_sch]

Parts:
C10: 33u; CP_Radial_D8.0mm_P2.50mm
C11: 10u; CP_Radial_D8.0mm_P2.50mm
D6: PWR; LED_D3.0mm
D7: 1N5817; D_DO-41_SOD81_P10.16mm_Horizontal
J7: 5V; PinHeader_1x02_P2.54mm_Vertical
J8: PWR; PinHeader_1x03_P2.54mm_Vertical
J9: 13.8V MAX; BarrelJack_GCT_DCJ200-10-A_Horizontal
R19: 200; R_1206_3216Metric
U1: LM7805; TO-220-3_Vertical

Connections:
5V: C11.1, J7.1, U1.3 (VO); also elsewhere on the board
GND: C10.2, C11.2, J7.2, J8.1, J8.3, J9.2, R19.1, U1.2 (GND); also elsewhere on the board
unnamed: D6.1 (K), R19.2
VCC: C10.1, D6.2 (A), D7.1 (K), U1.1 (VI); also elsewhere on the board
VIN: D7.2 (A), J8.2, J9.1

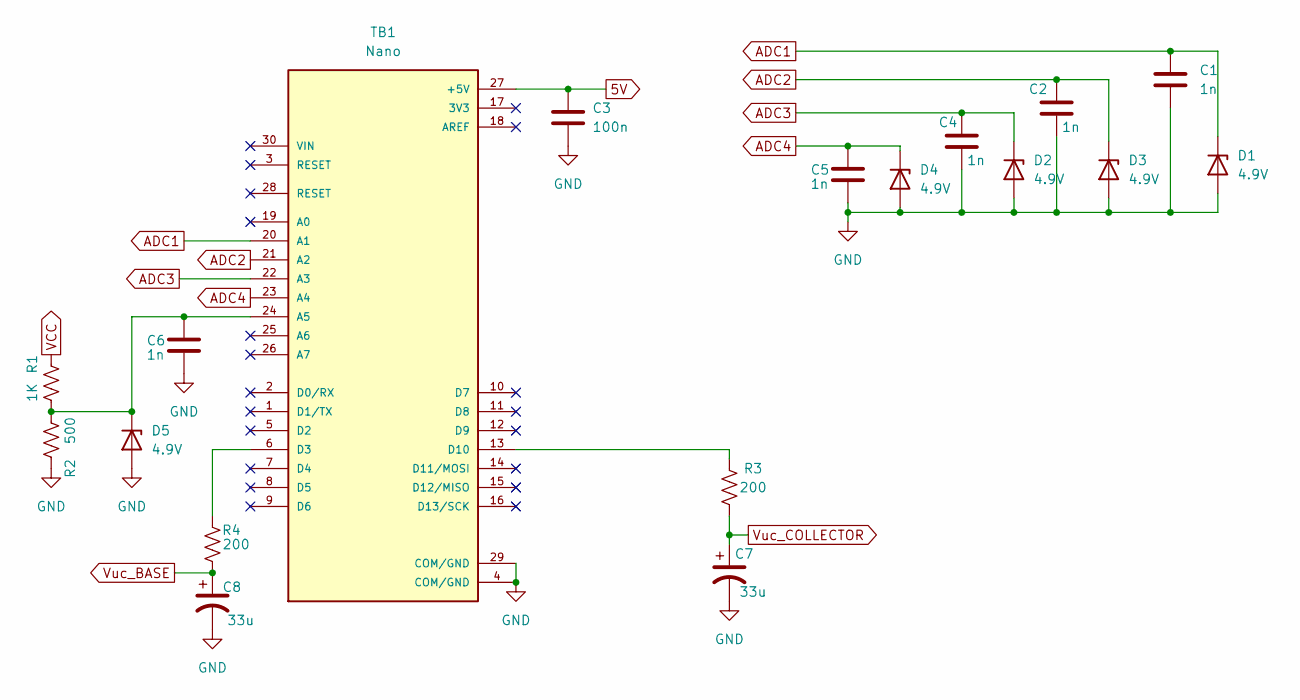
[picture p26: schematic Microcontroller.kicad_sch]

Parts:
C1, C2, C4, C5, C6: 1n; C_1206_3216Metric
C3: 100n; C_1206_3216Metric
C7, C8: 33u; CP_Radial_D8.0mm_P2.50mm
D1, D2, D3, D4, D5: 4.9V; D_SOD-323
R1: 1K; R_1206_3216Metric
R2: 500; R_1206_3216Metric
R3, R4: 200; R_1206_3216Metric
TB1: Nano; SHIELD_ARDUINO_NANO

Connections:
5V: C3.1, TB1.27 (+5V); also elsewhere on the board
ADC1: C1.1, D1.1 (K), TB1.20 (A1); also elsewhere on the board
ADC2: C2.1, D3.1 (K), TB1.21 (A2); also elsewhere on the board
ADC3: C4.1, D2.1 (K), TB1.22 (A3); also elsewhere on the board
ADC4: C5.1, D4.1 (K), TB1.23 (A4); also elsewhere on the board
GND: C1.2, C2.2, C3.2, C4.2, C5.2, C6.2, C7.2, C8.2, D1.2 (A), D2.2 (A), D3.2 (A), D4.2 (A), D5.2 (A), R2.2, TB1.4 (COM/GND), TB1.29 (COM/GND); also elsewhere on the board
unnamed: C6.1, D5.1 (K), R1.1, R2.1, TB1.24 (A5)
unnamed: R3.2, TB1.13 (D10)
unnamed: R4.2, TB1.6 (D3)
VCC: R1.2; also elsewhere on the board
Vuc_BASE: C8.1, R4.1; also elsewhere on the board
Vuc_COLLECTOR: C7.1, R3.1; also elsewhere on the board

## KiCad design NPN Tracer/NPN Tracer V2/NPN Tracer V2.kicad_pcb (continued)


Board: 2 copper layers, 99.1 x 69.5 mm, 63 parts (0 on the bottom side), 34 nets.

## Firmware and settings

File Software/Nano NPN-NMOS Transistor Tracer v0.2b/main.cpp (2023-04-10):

#include "main.h"

#include <Arduino.h>
#include <EEPROM.h>

#include "UART.h"  // VE3OOI Serial Interface Routines (TTY Commands)
#include "defines.h"
#include "help.h"
#include "nfet.h"
#include "npn.h"
#include "trace.h"

// These variables are defined in UART.cpp and used for Serial interface
// rbuff is used to store all keystrokes which is parsed by Execute()
// commands[] and numbers[] store all characters or numbers entered provided
// they are separated by spaces. ctr is counter used to process entries
// command_entries contains the total number of charaters/numbers entered
extern char rbuff[RBUFF];
extern char commands[MAX_COMMAND_ENTRIES];
extern unsigned char command_entries;
extern unsigned long numbers[MAX_COMMAND_ENTRIES];
extern unsigned char ctr;

extern char prompt[6];
extern char ovflmsg[9];
extern char errmsg[4];

unsigned long flags = 0;
unsigned int errorcode = 0;

int temp = 0;

float vtemp = 0;
float ctemp = 0;
int i = 0;
unsigned int addr = 0;  // EEPROM starting address for calibration strut

struct TRACE_TRANS_STRUT *pts;
struct TRACE_FET_STRUT *pfs;

void setup() {
  Serial.begin(9600);

  pfs = (TRACE_FET_STRUT *)malloc(sizeof(TRACE_FET_STRUT));
  pts = (TRACE_TRANS_STRUT *)pfs;
  memset((char *)pfs, 0, sizeof(TRACE_FET_STRUT));

  Reset();
  setDefaultLimits();

  addr = 0;
  EEPROM.get(addr, *pfs);

  if (pfs->version != EEPROM_HEADER) {
    Serial.println("EE INIT");
    setDefaultLimits();
    pts->rcResistor = RC_RESISTORHIGH;
    pts->rbResistor = RB_RESISTOR;
    getMinMaxVoltages();
    EEPROM.put(addr, *pfs);
  }

  waitForVcc(CHECK_ANALOG_VCC);
  Serial.println("EE OK");
  printConfig(ALL_VALUES);
  Serial.print("Vcc Ok.  Vcc: ");
  vtemp = getVccVoltage();
  Serial.println(vtemp, 1);

  Serial.write(prompt);
}

void loop() {
  if (checkVcc(CHECK_DIGITAL_VCC)) {
    Serial.println("Vcc Off");
    for (i = 0; i < 5; i++) {
      digitalWrite(LED_BUILTIN, HIGH);
      delay(500);
      digitalWrite(LED_BUILTIN, LOW);
      delay(500);
    }
  } else {
    // Look for characters entered from the keyboard and process them
    // This function is part of the UART package.
    processSerial();
  }

  if (flags & PRINT_ADC_VALUES) {
    temp = adcAverage(pts->VccVoltagePin, ADC_BIT_SHIFT_AVERAGE);
    Serial.print(temp);
    Serial.print("\t");

    temp = adcAverage(pts->VcVoltagePin, ADC_BIT_SHIFT_AVERAGE);
    Serial.print(temp);
    Serial.print("\t");

    temp = adcAverage(pts->Vb1VoltagePin, ADC_BIT_SHIFT_AVERAGE);
    Serial.print(temp);
    Serial.print("\t");

    temp = adcAverage(pts->Vb2VoltagePin, ADC_BIT_SHIFT_AVERAGE);
    Serial.println(temp);

  } else if (flags & SWEEP_BJT_OUTPUT_DATA) {
    Serial.println("BJT Output Sweep");
    printUnits();
    doOutputNPNSweep();
    Serial.write(prompt);

  } else if (flags & SWEEP_BJT_INPUT_DATA ||
             flags & SWEEP_BJT_INPUT_DATA_BY_VCE) {
    Serial.println("BJT Input Sweep");
    printUnits();
    doNPNInputSweep();
    Serial.write(prompt);

  } else if (flags & SWEEP_BJT_BETA_DATA || flags & SWEEP_BJT_BETAC_DATA ||
             flags & SWEEP_BJT_RE_DATA || flags & SWEEP_BJT_GM_DATA) {
    Serial.println("NPN Beta/Re/Gm Sweep");
    printUnits();
    doNPNBetaSweep();
    Serial.write(prompt);

  } else if (flags & SWEEP_DIODE_INPUT_DATA) {
    Serial.println("Diode Input Sweep");
    printUnits();
    doNPNInputSweep();
    Serial.write(prompt);

  } else if (flags & SWEEP_DIODE_OUTPUT_DATA) {
    Serial.println("Diode Output Sweep");
    printUnits();
    doDiodeOutputSweep();
    Serial.write(prompt);

  } else if (flags & SWEEP_FET_INPUT_DATA ||
             flags & SWEEP_FET_VOLTAGE_INPUT_DATA || flags & SWEEP_FET_R_DATA) {
    Serial.println("FET Input Sweep");
    printUnits();
    doNPNInputSweep();
    Serial.write(prompt);

  } else if (flags & SWEEP_FET_OUTPUT_DATA) {
    Serial.println("FET Output Sweep");
    printUnits();
    doOutputFETSweep();
    Serial.write(prompt);

  } else if (flags & SWEEP_FET_K_DATA || flags & SWEEP_FET_GM_DATA) {
    Serial.println("FET K/GM Sweep");
    printUnits();
    doFETKSweep();
    Serial.write(prompt);
  }
}

void printUnits(void) {
  if (pfs->units == 'M' || pfs->units == 'M') {
    Serial.println("Units: m");
  } else if (pfs->units == 'U' || pfs->units == 'U') {
    Serial.println("Units: u");
  }
}

void Reset(void) {
  resetPins();
  resetVoltages();

  printBanner();
  resetSerial();
  Serial.write(prompt);
}

// Place program specific content here
void executeSerial(char *str) {
  // This function called when serial input in present in the serial buffer
  // The serial buffer is parsed and characters and numbers are scraped and
  // entered in the commands[] and numbers[] variables.
  parseSerial(str);

  // Process the commands
  // Note: Whenever a parameter is stated as [CLK] the square brackets are not
  // entered. The square brackets means that this is a command line parameter
  // entered after the command. E.g. F [n] [m] would be mean "F 0 7000000" is
  // entered (no square brackets entered)
  switch (commands[0]) {
      ////////////////////////////////////////////////////////////
      //////// CALIBRATION
      ////////////////////////////////////////////////////////////
    case 'C':                    // Calibrate
      if (commands[1] == 'R') {  // read raw ADC values
        if (flags & PRINT_ADC_VALUES) {
          flags &= ~PRINT_ADC_VALUES;
        } else {
          flags &= ~EXPORT_DATA;
          flags |= PRINT_ADC_VALUES;
        }
      } else if (commands[1] == 'M') {
        if (!checkResistors(ALL_VALUES, 1)) {
          break;
        }
        getMinMaxVoltages();
      } else {
        printConfig(ALL_VALUES);
      }
      break;

      ////////////////////////////////////////////////////////////
      //////// Set defaults
      ////////////////////////////////////////////////////////////
    case 'D':  // Defaults
      setDefaultLimits();
      pts->rcResistor = RC_RESISTORHIGH;
      pts->rbResistor = RB_RESISTOR;
      printConfig(ALL_VALUES);
      break;

      ////////////////////////////////////////////////////////////
      //////// Set defaults
      ////////////////////////////////////////////////////////////
    case 'E':                    // EEPROM
      if (commands[1] == 'R') {  // Read EEPROM ADC values
        EEPROM.get(addr, *pfs);

      } else if (commands[1] == 'I') {  // Initialize EEPROM ADC values{
        Serial.println("EE INIT");
        setDefaultLimits();
        pts->rcResistor = RC_RESISTORHIGH;
        pts->rbResistor = RB_RESISTOR;
        getMinMaxVoltages();
        EEPROM.put(addr, *pfs);

        delay(500);  // Allow time for write to complete
        EEPROM.get(addr, *pfs);
        if (pfs->version == EEPROM_HEADER) {
          Serial.println("EE check ok\r\n");
        } else {
          Serial.println("EE Err");
          break;
        }

      } else if (commands[1] == 'W') {  // Initialize EEPROM ADC values{
        if (!checkResistors(ALL_VALUES, 0) || !checkSweepRange()) {
          Serial.println("Config Err");
          break;
        }
        EEPROM.put(addr, *pfs);
        delay(500);  // give delay to allow to complete
        EEPROM.get(addr, *pfs);
      }
      if (pfs->version == EEPROM_HEADER) {
        printConfig(ALL_VALUES);
      } else {
        Serial.println("EE Err");
      }
      break;

      ////////////////////////////////////////////////////////////
      //////// Help
      ////////////////////////////////////////////////////////////
    case 'H':  // Help
      printHelp();
      break;

      ////////////////////////////////////////////////////////////
      //////// Measure Voltages
      ////////////////////////////////////////////////////////////
    case 'M':  // Measure voltages
      Serial.println("NPN: ");
      measureVoltages();
      displayVoltages();
      break;

      ////////////////////////////////////////////////////////////
      //////// PWM Output
      ////////////////////////////////////////////////////////////
    case 'P':  // SET PWM
      if ((numbers[0] != (unsigned long)pts->VbOutPin &&
           numbers[0] != (unsigned long)pts->VccOutPin) ||
          numbers[1] > 255) {
        Serial.println("Num Err");
        break;
      }
      Serial.print("Pin ");
      Serial.print(numbers[0]);
      Serial.print(" PWM ");
      Serial.println(numbers[1]);
      analogWrite((int)numbers[0], (int)numbers[1]);
      break;

      ////////////////////////////////////////////////////////////
      //////// Reset
      ////////////////////////////////////////////////////////////
    case 'R':  // Reset
      Reset();
      break;

      ////////////////////////////////////////////////////////////
      //////// Set Parameters
      ////////////////////////////////////////////////////////////
    case 'S':  // Set current or voltage
      /*
      =============================================================
      Set Output Base current on pin numbers[0]
      =============================================================
      */
      if (commands[1] == 'V') {
        if (!checkResistors(ALL_VALUES, 1)) {
          break;
        }
        if (pts->VbControlMax == 0 || pts->VcControlMax == 0) {
          Serial.println("Cal Err");
          break;
        }
        temp = 0;
        ctemp = vtemp = 0;
        vtemp = (float)numbers[0] / (float)1000;
        if (commands[2] == 'B') {
          temp = pts->VbOutPin;
          ctemp = pts->VbControlMax * 1000;
          if (numbers[0] > (unsigned long)ctemp || numbers[0] == 0) {
            Serial.print("mV <");
            Serial.println((unsigned long)ctemp);
            break;
          }
        } else if (commands[2] == 'C') {
          temp = pts->VccOutPin;
          ctemp = pts->VcControlMax * 1000;
          if (numbers[0] > (unsigned long)ctemp || numbers[0] == 0) {
            Serial.print("mV <");
            Serial.println((unsigned long)ctemp);
            break;
          }
        } else {
          printError(CMDERR);
          break;
        }

        Serial.print("Pin ");
        Serial.print(temp);
        Serial.print(" mV ");
        Serial.println(vtemp, 1);
        Serial.println(" mV");

        setVoltage(temp, vtemp);
        delay(PWM_SETTLE_TIME);  // First voltage take a while to charge
                                 // capacitor.  Change from 30 to 40ms
        measureVoltages();
        displayVoltages();
        break;

        /*
        =============================================================
        Set Resistor values for Base & Collector
        =============================================================
        */
      } else if (commands[1] == 'R') {  // Set Resistor

        ////// Collector resistor
        if (commands[2] == 'C') {
          if (numbers[0] != RC_RESISTORLOW && numbers[0] != RC_RESISTORHIGH) {
            Serial.print("R ");
            Serial.print(RC_RESISTORLOW);
            Serial.print("|");
            Serial.print(RC_RESISTORHIGH);
            Serial.print(" Err");
            break;
          }
          pts->rcResistor = (int)numbers[0];
          printResistorValues(COLLECTOR_VALUES);
          break;
          ////// Base resistor
        } else if (commands[2] == 'B') {
          if (numbers[0] != RB_RESISTOR) {
            Serial.println("Set 'RB_RESISTOR' in defines.h");
            break;
          }
          pts->rbResistor = (int)numbers[0];
          printResistorValues(BASE_VALUES);
          break;
        } else {
          printResistorValues(ALL_VALUES);
        }
        /*
        =============================================================
        set data points in sweep
        =============================================================
        */
      } else if (commands[1] == 'P') {  // Set Sweep increment
                                        ////// Base points
        if (commands[2] == 'B') {
          if (numbers[0] < MIN_NUM_VB_VOLTAGE ||
              numbers[0] > MAX_NUM_VB_VOLTAGE) {
            Serial.print("P >");
            Serial.print(MIN_NUM_VB_VOLTAGE);
            Serial.print(" & <");
            Serial.print(MAX_NUM_VB_VOLTAGE);
            Serial.print(" Err");
            break;
          }
          pts->nvb = (int)numbers[0];
          Serial.print("B/G: ");
          Serial.println(pts->nvb);
          pts->VbControlInc =
              (pts->VbControlMax - pts->VbControlMin) / (float)pts->nvb;
          break;
          ////// Collector points
        } else if (commands[2] == 'C') {
          if (numbers[0] < MIN_NUM_VC_VOLTAGE ||
              numbers[0] > MAX_NUM_VC_VOLTAGE) {
            Serial.print("P >");
            Serial.print(MIN_NUM_VC_VOLTAGE);
            Serial.print(" & <");
            Serial.print(MAX_NUM_VC_VOLTAGE);
            Serial.print(" Err");
            break;
          }
          pts->nvc = (int)numbers[0];
          Serial.print("C/D: ");
          Serial.println(pts->nvc);
          pts->VcControlInc =
              (pts->VcControlMax - pts->VcControlMin) / (float)pts->nvc;
          break;
        } else {
          Serial.print("B/G: ");
          Serial.print(pts->nvb);
          Serial.print(" C/D: ");
          Serial.println(pts->nvc);
        }
        /*
        =============================================================
        set default units for sweep values
        =============================================================
        */
      } else if (commands[1] == 'U') {  // set default Units
        if (commands[2] != 'M' && commands[2] != 'U' && commands[2] != 'D') {
          Serial.print("Units: ");
          Serial.println(pts->units);
          break;
        }
        pts->units = pfs->units = commands[2];
        Serial.print("Units: ");
        Serial.println(pts->units);
        break;
        /*
        =============================================================
        set min max Vb and Vg input voltages to sweep (i.e. voltages generated
        by arduino)
        =============================================================
        */
      } else if (commands[1] ==
                 'I') {  // set min max Vb and Vg voltages to sweep
                         ////// Base Voltage
        if (commands[2] == 'B') {
          if (numbers[0] >= numbers[1] ||
              numbers[0] > (unsigned long)(MAX_VB_VOLTAGE * 1000) ||
              numbers[1] > (unsigned long)(MAX_VB_VOLTAGE * 1000) ||
              numbers[0] < (unsigned long)(MIN_VB_VOLTAGE * 1000) ||
              numbers[1] < (unsigned long)(MIN_VB_VOLTAGE * 1000) ||
              numbers[1] == 0) {
            printError(NUMERR);
            break;
          }
          pts->VbControlMin = ((float)numbers[0]) / 1000.0;
          pts->VbControlMax = ((float)numbers[1]) / 1000.0;
          pts->VbControlInc =
              (pts->VbControlMax - pts->VbControlMin) / (float)pts->nvb;
          printControlValues(BASE_VALUES);
          ////// Collector Voltage
        } else if (commands[2] == 'C') {
          if (numbers[0] >= numbers[1] ||
              numbers[0] > (unsigned long)(MAX_VC_VOLTAGE * 1000) ||
              numbers[1] > (unsigned long)(MAX_VC_VOLTAGE * 1000) ||
              numbers[0] < (unsigned long)(MIN_VC_VOLTAGE * 1000) ||
              numbers[1] < (unsigned long)(MIN_VC_VOLTAGE * 1000) ||
              numbers[1] == 0) {
            printError(NUMERR);
            break;
          }
          pts->VcControlMin = ((float)numbers[0]) / 1000.0;
          pts->VcControlMax = ((float)numbers[1]) / 1000.0;
          pts->VcControlInc =
              (pts->VcControlMax - pts->VcControlMin) / (float)pts->nvc;
          printControlValues(COLLECTOR_VALUES);
        } else {
          printControlValues(ALL_VALUES);
        }
        break;
        /*
        =============================================================
        set min max Vb and Vg output voltages to sweep (i.e. voltages delivered
        to DUT)
        =============================================================
        */
      } else if (commands[1] ==
                 'O') {  // set min max OUTPUT Vb and Vg voltages to sweep

        if (pts->VbControlMax == 0 || pts->VcControlMax == 0 ||
            pts->vbmax == 0 || pts->vcmax == 0 || pts->bSlope == 0 ||
            pts->cSlope == 0) {
          Serial.println("Cal Err");
          break;
        }

        if (commands[2] == 'C') {
          if (numbers[0] >= numbers[1] ||
              numbers[0] > (unsigned long)(pts->vcmax * 1000) ||
              numbers[1] > (unsigned long)(pts->vcmax * 1000) ||
              numbers[0] < (unsigned long)(pts->vcmin * 1000) ||
              numbers[1] < (unsigned long)(pts->vcmin * 1000) ||
              numbers[1] == 0) {
            printError(NUMERR);
            break;
          }
          pts->VcControlMin = convertOutputToControl((float)numbers[0] / 1000,
                                                     COLLECTOR_VALUES);
          pts->VcControlMax = convertOutputToControl((float)numbers[1] / 1000,
                                                     COLLECTOR_VALUES);
          pts->VcControlInc =
              (pts->VcControlMax - pts->VcControlMin) / (float)pts->nvc;
          printControlValues(COLLECTOR_VALUES);
          printOutputVoltageValues(COLLECTOR_VALUES);
          break;
          ////// Collector Voltage
        } else if (commands[2] == 'B') {
          if (numbers[0] >= numbers[1] ||
              numbers[0] > (unsigned long)(pts->vbmax * 1000) ||
              numbers[1] > (unsigned long)(pts->vbmax * 1000) ||
              numbers[0] < (unsigned long)(pts->vbmin * 1000) ||
              numbers[1] < (unsigned long)(pts->vbmin * 1000) ||
              numbers[1] == 0) {
            printError(NUMERR);
            break;
          }
          pts->VbControlMin =
              convertOutputToControl((float)numbers[0] / 1000, BASE_VALUES);
          pts->VbControlMax =
              convertOutputToControl((float)numbers[1] / 1000, BASE_VALUES);
          pts->VbControlInc =
              (pts->VbControlMax - pts->VbControlMin) / (float)pts->nvb;
          printControlValues(BASE_VALUES);
          printOutputVoltageValues(BASE_VALUES);
          break;
        } else {
          printControlValues(ALL_VALUES);
          printOutputVoltageValues(ALL_VALUES);
          break;
        }
      } else {
        clearSweepFlags();
        printError(CMDERR);
      }
      break;
      ////////////////////////////////////////////////////////////
      //////// Trace
      ////////////////////////////////////////////////////////////
    case 'T':           // Trace
      pts->header = 0;  // set to show trace header

      /*
      =============================================================
      NPN BJT Traces
      =============================================================
      */
      if ((!checkResistors(ALL_VALUES, 1)) || !checkSweepRange()) {
        break;
      }

      if (commands[1] == 'N') {
        flags = flags | EXPORT_DATA;
        if (commands[2] == 'I') {  // Input sweep by VCE or base voltage
          if (commands[3] == 'V') {
            flags = flags | SWEEP_BJT_INPUT_DATA_BY_VCE;
          } else {
            flags = flags | SWEEP_BJT_INPUT_DATA;
          }
        } else if (commands[2] == 'O') {  // Output Sweep
          flags = flags | SWEEP_BJT_OUTPUT_DATA;
        } else if (commands[2] == 'B') {
          if (commands[3] == 'C') {
            flags = flags | SWEEP_BJT_BETAC_DATA;
          } else {
            flags = flags | SWEEP_BJT_BETA_DATA;
          }
        } else if (commands[2] == 'R') {  // Re Sweep
          flags = flags | SWEEP_BJT_RE_DATA;
        } else if (commands[2] == 'G') {  // Output Sweep
          flags = flags | SWEEP_BJT_GM_DATA;

        } else {
          clearSweepFlags();
          printError(CMDERR);
        }

        /*
        =============================================================
        Diode Traces
        =============================================================
        */
      } else if (commands[1] == 'D') {
        flags = flags | EXPORT_DATA;
        if (commands[2] == 'I') {
          flags = flags | SWEEP_DIODE_INPUT_DATA;
        } else if (commands[2] == 'O') {
          flags = flags | SWEEP_DIODE_OUTPUT_DATA;
        } else {
          clearSweepFlags();
          printError(CMDERR);
        }

        /*
        =============================================================
        NMOS FET Traces
        =============================================================
        */
      } else if (commands[1] == 'F') {
        flags = flags | EXPORT_DATA;
        if (commands[2] == 'I') {
          if (commands[3] == 'V') {
            flags = flags | SWEEP_FET_VOLTAGE_INPUT_DATA;
          } else {
            flags = flags | SWEEP_FET_INPUT_DATA;
          }
        } else if (commands[2] == 'O') {
          flags = flags | SWEEP_FET_OUTPUT_DATA;
        } else if (commands[2] == 'K') {
          flags = flags | SWEEP_FET_K_DATA;
        } else if (commands[2] == 'G') {
          flags = flags | SWEEP_FET_GM_DATA;
        } else if (commands[2] == 'R') {
          flags = flags | SWEEP_FET_R_DATA;
        } else {
          clearSweepFlags();
          printError(CMDERR);
        }

      } else {
        clearSweepFlags();
        printError(CMDERR);
      }
      break;

    // If an undefined command is entered, display an error message
    default:
      printError(CMDERR);
  }
}

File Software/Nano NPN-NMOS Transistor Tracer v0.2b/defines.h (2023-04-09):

#ifndef _DEFINES_H_
#define _DEFINES_H_

#include <arduino.h>

#define EEPROM_HEADER 0xA2

#define FLASH_HELP    // Load help in flash so its not stored in RAM
#define VERBOSE_HELP  // Verbose help messages - used up more memory


#define FLASH_HELP    // Load help in flash so its not stored in RAM
#define VERBOSE_HELP  // Verbose help messages - used up more memory


// Pin Definations
#define VCCADC A4           // NPN Vcc measure voltage.  Was A1
#define VCADC A3            // NPN Vc measure voltage. Was A2
#define VB1ADC A1           // NPN Vb1 measure voltage. Was A3
#define VB2ADC A2           // NPN Vb2 measure voltage. WAS A4
#define VCC_CONTROL_PIN 10  // PWM NPN Vc controlOutput pin
#define VB_CONTROL_PIN 3    // PWM NPN Vb control Output pin
#define VCC_DIGITAL_PIN 12  // Digital sense pin for Vcc is connected
#define VCC_ANALOG_PIN A0   // Vcc voltage measurement

/*
ADC Calibration

1) Apply 5 volts to each POT
2) Set voltage read at wiper to about 1.75
3) Connect Arduino and read ADC values
4) Adjust pot to get about 364
5) Calculate divider, adc_conv, v_conv
6) Change ADC_CONVERSION to be v_conv
7) if Pots are changes must redo this

Example:
ADC4, ADC3, ADC2, ADC1 = comma separated
Vapplied: 4.9V,4.9,4.76,4.86
Vadc: 1.755,1.753,1.701,1.74
ADC:364,364,353,362

Divider(avg) = Vadc/Vapplied =  0.3575
ADC_Conv(AVG) = ADC/Vadc = 207.7
V_conv = Divider*ADC_Conv = 74.22
Vmeasured = ADC / V_conv
*/

#define ADC_CONVERSION ((float)74.22)

#define LOW_ADC_CONVERSION ((float)74.22)

// #define PWM_SCALING  ((float)11.3 / (float)4.6)  // was ((float)11.3 /
// (float)4.6)

// Need to scale the voltage to an PWM signal which is 0-255 (8 bits)
// Make some assumptions.  Make max voltage 598 and scale values relative to
// this.
#define VOLTAGE_SCALING 128
#define MAX_SCALED_VOLTAGE (589)  // 4.6*128

/*
Resistor divider is 991 and 497. Divider is 497/(497+991)=0.3340
ADC Voltage conversion is 4.88V/1024 so 1 ADC count is 4.766mV
With resistive divider each count is actually 4.766mV/0.3340 = 14.26mV =
0.01426V
*/
#define VOLTAGE_SENSE_CONVERSION \
  0.01426  // V per count.  Multiply by ADC counts to get voltage in V
#define MAX_ALLOWED_VCC_VOLTAGE \
  14  // Any voltage above this could damage arduino
#define MIN_ALLOWED_VCC_VOLTAGE \
  8  // Arbituary set.  Vcc of 9 volts is barely usable

#define MAX_VC_VOLTAGE 4.6
#define MIN_VC_VOLTAGE 0.010
#define NUM_VC_VOLTAGE 15
#define MIN_NUM_VC_VOLTAGE 5
#define MAX_NUM_VC_VOLTAGE 20
#define ERROR_VC_VOLTAGE 0.009

#define MAX_VB_VOLTAGE 4.6
#define MIN_VB_VOLTAGE 0
#define NUM_VB_VOLTAGE 10
#define MIN_NUM_VB_VOLTAGE 5
#define MAX_NUM_VB_VOLTAGE 20

#define CALIBRATION_VC_VOLTAGE 4.6
#define CALIBRATION_VB_VOLTAGE 2.3
#define VOLTAGE_ON_THRESHOLD 0.1
#define PWM_RESOLUTION 0.02  // This is max PWM pin voltage/255, for 4.9V, this is 0.02 

#define THERMAL_VOLTAGE 0.026

#define RC_RESISTORHIGH 32
#define RC_RESISTORLOW 10
#define RB_RESISTOR 462

#define PWM_SETTLE_TIME 40  // Was 30ms
#define ADC_BIT_SHIFT_AVERAGE 7

#define BASE_VALUES 'B'
#define COLLECTOR_VALUES 'C'
#define ALL_VALUES 'A'
#define INPUT_SWEEP_VALUES 'I'

#define QUIET 0
#define PUKE 1
#define CHECK_ANALOG_VCC 1
#define CHECK_DIGITAL_VCC 0

#define SWEEP_BJT_INPUT_DATA 0x00000001
#define SWEEP_BJT_OUTPUT_DATA 0x00000002
#define SWEEP_BJT_INPUT_DATA_BY_VCE 0x00000004
#define SWEEP_BJT_BETA_DATA 0x00000008
#define SWEEP_BJT_BETAC_DATA 0x00000010
#define SWEEP_BJT_RE_DATA 0x00000020
#define SWEEP_BJT_GM_DATA 0x00000040
///////////////
#define SWEEP_FET_INPUT_DATA 0x00000080
#define SWEEP_FET_OUTPUT_DATA 0x00000100
#define SWEEP_FET_VOLTAGE_INPUT_DATA 0x00000200
#define SWEEP_FET_K_DATA 0x00000400
#define SWEEP_FET_GM_DATA 0x00000800
#define SWEEP_FET_R_DATA 0x00001000
//////////////
#define SWEEP_DIODE_INPUT_DATA 0x00002000
#define SWEEP_DIODE_OUTPUT_DATA 0x00004000
//////////////
#define PRINT_ADC_VALUES 0x00100000
#define EXPORT_DATA 0x00200000

#endif  // _DEFINES_H_

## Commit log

2023-03-29 Initial Hardware Files
    [Microcontroller.kicad_sch, NPN Tracer V1 BOM.xlsx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]
2023-03-30 Add Python Graphing Program
    [2N3904 Voltage Amp - Calibration.xlsx, Data.ods, Transistor Trace Data (new).ods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]
2023-03-30 Code update 30Mar23
    [2N3904 Voltage Amp - Calibration.xlsx]
2023-05-07 Update 7May23
    [Microcontroller.kicad_sch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]
2023-05-08 Update 8May23
    [NPN Tracer V1 BOM.xlsx, NPN Tracer V1.csv, NPN Tracer V1.kicad_pcb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]
